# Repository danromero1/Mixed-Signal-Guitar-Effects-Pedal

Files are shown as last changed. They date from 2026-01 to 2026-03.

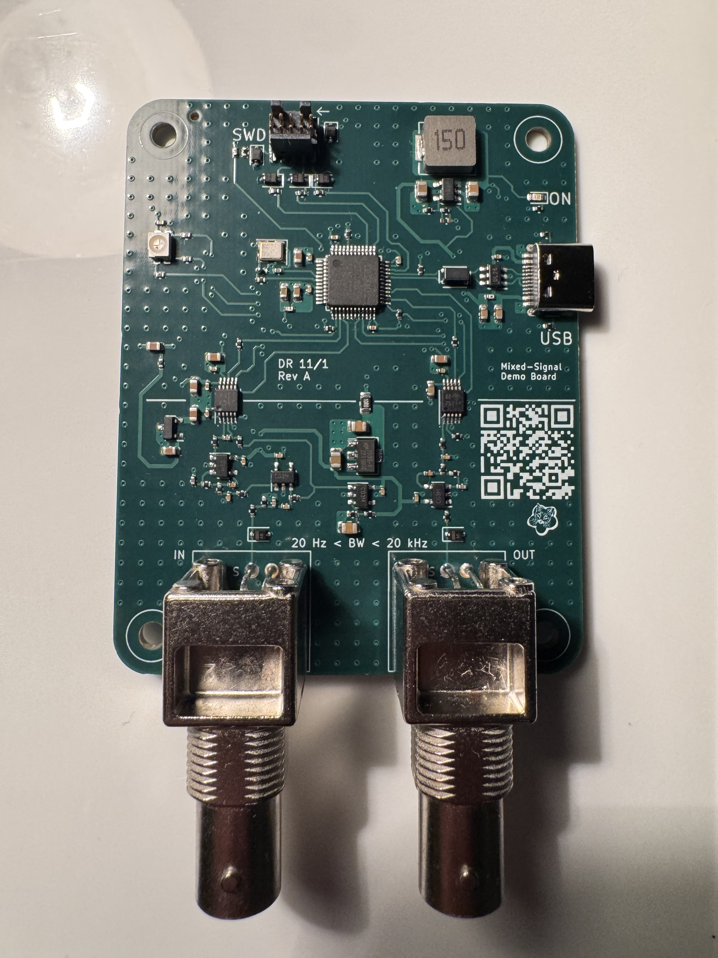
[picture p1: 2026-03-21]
docs/images/assembled_board.png

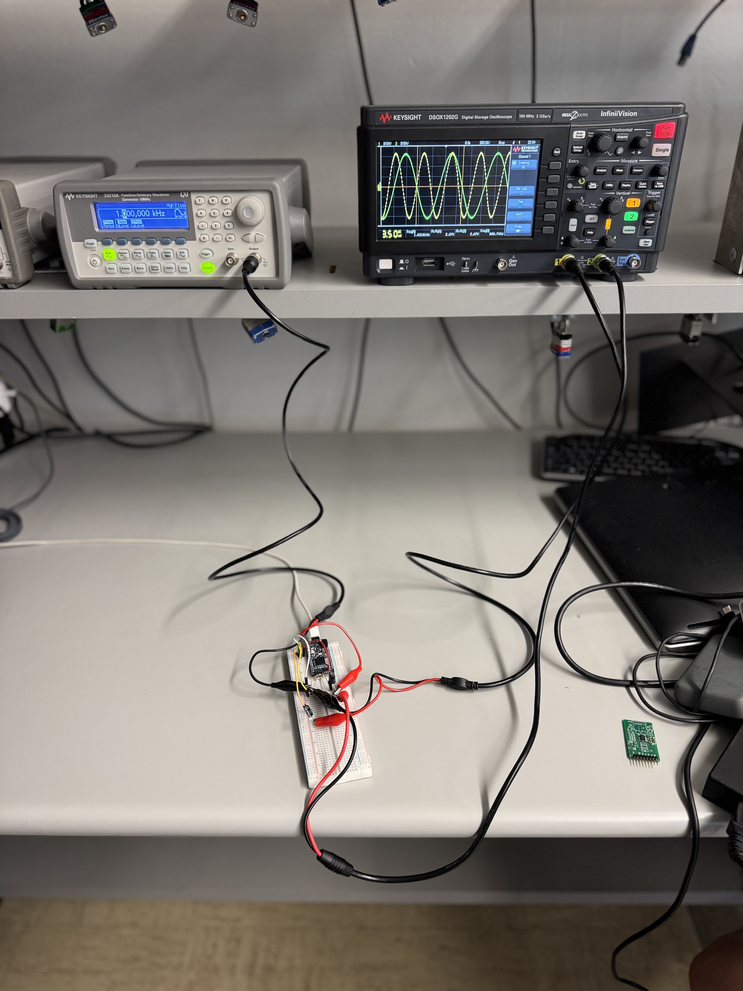
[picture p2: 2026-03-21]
docs/analysis/adc_dma_dac_validation.jpg

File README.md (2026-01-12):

# Mixed-Signal Guitar Effects Pedal





A standalone programmable guitar effects pedal implemented on a custom mixed-signal embedded platform with real-time DSP processing on an STM32 microcontroller.

---

## Overview

This project is the end-to-end design and bring-up of a custom 4-layer mixed-signal embedded platform for real-time audio acquisition, digital signal processing, and playback. An external high-resolution ADC and DAC interface with an STM32 microcontroller to enable deterministic, low-latency audio processing in a standalone system operating without a host PC.

The analog front end provides a high-impedance guitar input stage, precision biasing, and a 3rd-order Butterworth anti-aliasing filter to condition signals prior to conversion. Reconstruction filtering and low-noise output buffering suppress imaging artifacts and maintain low distortion across the audible band. PCB layout emphasizes controlled return paths, analog–digital domain isolation, low-impedance grounding, and consistent impedance to minimize coupling between sensitive analog circuitry and high-speed digital switching.

Power delivery is implemented using a USB-C input feeding a multi-rail regulation architecture to support low-noise analog supplies and regulated digital rails. All power stages and filter networks were simulated and validated in LTspice prior to layout. Decoupling and bypass networks were optimized per device requirements to ensure supply stability under dynamic load conditions.

Firmware is developed bare-metal in STM32CubeIDE using timer-triggered ADC sampling, DMA-based double buffering, and deterministic interrupt scheduling. Digital signal processing algorithms—including soft-clipping distortion, equalization, and filtering—are implemented in C using the CMSIS-DSP library on a Cortex-M4 FPU platform. The system targets a 48 kHz sample rate with sub-5 ms end-to-end latency to preserve instrument responsiveness.

The platform serves as a practical environment for developing embedded firmware architecture, hardware–software co-design techniques, signal integrity practices, and real-time performance analysis while producing a functional guitar effects processor from schematic to working prototype.

---

## Key Objectives

- Design and validate a professional-grade mixed-signal PCB for low-noise audio applications  
- Implement deterministic real-time audio processing on embedded hardware  
- Develop practical experience with ADC/DAC interfacing, buffering, and latency management  
- Integrate hardware bring-up, firmware development, and signal characterization into a complete system  

---

## Features

### Hardware
- STM32 microcontroller with floating-point acceleration  
- External high-resolution ADC and DAC for audio conversion  
- 4-layer PCB optimized for signal integrity and power integrity  
- 3rd-order Butterworth analog anti-aliasing filter  
- USB-C powered multi-rail regulation architecture  

### DSP
- Bare-metal real-time audio pipeline  
- DMA-based double buffering  
- Soft-clipping distortion processing  
- Digital equalization and filtering  
- Deterministic sampling and low-latency operation  

---

## Technical Stack

### Hardware
- STM32 Microcontroller (ARM Cortex-M4 with FPU)  
- External high-resolution ADC and DAC  
- 4-layer PCB with controlled impedance and solid reference planes  
- USB-C power delivery and multi-rail regulation  

### Software & Tools
- KiCad – Schematic capture and PCB layout  
- STM32CubeIDE – Bare-metal firmware development  
- CMSIS-DSP – Optimized DSP library  
- LTspice – Circuit simulation and filter verification  
- C/C++ – Embedded firmware implementation  

---

## Design Process

### Circuit Design & Simulation
Analog input and output stages were designed for guitar signal conditioning, biasing, and bandwidth control. A 3rd-order Butterworth anti-aliasing filter was simulated and verified in LTspice along with ADC/DAC interfacing and power regulation networks.

### PCB Layout (4-Layer Stack-Up)

- **Layer 1:** Top signal layer (components, sensitive analog routing, high-speed digital signals)  
- **Layer 2:** Solid ground plane for low-impedance return paths and noise control  
- **Layer 3:** Secondary reference plane for shielding and analog/digital isolation  
- **Layer 4:** Bottom signal layer for routing and power distribution  

**Design considerations include:**
- Analog and digital domain isolation  
- Controlled impedance routing for high-speed signals  
- Low-inductance return paths and continuous reference planes  
- Robust decoupling and power integrity practices  

### Firmware Architecture

Firmware configures ADC, DAC, timers, DMA, and interrupt scheduling to form a deterministic real-time audio pipeline. Audio samples are acquired using timer-triggered ADC conversions, buffered via DMA, processed in interrupt callbacks, and streamed to the DAC with minimal jitter and latency.

DSP algorithms are implemented in C using CMSIS-DSP primitives and floating-point arithmetic to accelerate development and maintain numerical stability.

---

## Development Status

### Completed
- Schematic design and circuit simulation  
- 3rd-order Butterworth filter design and verification  
- 4-layer PCB layout and stack-up definition  
- Component selection and BOM creation  

### In Progress
- Bare-metal firmware development  
- Real-time DSP implementation  
- PCB fabrication and assembly  

### Planned
- Hardware bring-up and validation  
- Audio performance measurement and characterization  
- Enclosure design and mechanical integration  
- Additional DSP effects (chorus, delay, reverb)  

---

## Technical Specifications

### Audio Path
- Input Impedance: 1 MΩ  
- Sample Rate: 48 kHz  
- Bit Depth: 16–24 bit (ADC dependent)  
- Frequency Response: 20 Hz – 20 kHz  
- Anti-Aliasing Filter: 3rd-order Butterworth, fc ≈ 20 kHz  

### Power
- Input: USB-C (5 V)  
- Internal Rails: 3.3 V (digital), ±5 V or +9 V (analog)  
- Estimated Current Consumption: 200–300 mA  

### Processing
- MCU: STM32 ARM Cortex-M4 with FPU  
- Target End-to-End Latency: < 5 ms  

---

## Engineering Focus

This project provides hands-on experience in:

- Mixed-signal PCB design and layout techniques  
- Real-time embedded firmware development  
- DMA-based buffering and interrupt-driven architectures  
- Analog signal conditioning and filter design  
- Audio signal processing fundamentals  
- Hardware bring-up and debugging on custom PCBs  
- Hardware–software co-design tradeoffs  

---

## Roadmap

### Phase 1 — Core Development (Current)
- Complete DSP firmware implementation  
- Fabricate and assemble PCB  
- Initial bring-up and debugging  

### Phase 2 — Refinement
- Audio performance characterization  
- Latency and CPU utilization optimization  
- PCB revision based on test results  

### Phase 3 — Enhancement
- Additional DSP effects  
- USB parameter control interface  
- Enclosure design and fabrication  

---

## References

### DSP
- *The Scientist and Engineer's Guide to Digital Signal Processing* — Steven W. Smith  
- *Understanding Digital Signal Processing* — Richard G. Lyons  
- *Small Signal Audio Design* — Douglas Self  

### Application Notes
- STM32 Audio Processing Application Notes  
- High-Speed PCB Design Guidelines  
- Audio ADC/DAC Interface Best Practices  

---

## License

This project is licensed under the MIT License. See the [LICENSE](LICENSE) file for details.

---

## Contact

**Daniel Romero**  
Email: daniel.romero@ieee.org  
Portfolio: https://electricalromero.com  
LinkedIn: https://www.linkedin.com/in/daniel-romero-ee/  

---

_Last updated: January 2026_

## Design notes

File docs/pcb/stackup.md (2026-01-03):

# PCB Stackup

This board uses a 4-layer stackup optimized for mixed-signal audio processing and embedded digital systems.

## Layer Configuration

| Layer | Name | Function |
|---:|---|---|
| L1 | Top (F.Cu)  | Signal routing and component placement |
| L2 | Inner 1 | Solid ground plane |
| L3 | Inner 2 | Solid ground plane |
| L4 | Bottom (B.Cu) | Secondary signal routing and low-speed interconnects |

## Design Rationale

- Dual internal ground planes provide low-inductance return paths for both analog and digital signals.
- Continuous, unbroken ground planes minimize EMI, ground bounce, and noise coupling in mixed-signal paths.
- Analog and digital circuits reference the same ground system to avoid return-path discontinuities.
- Critical signal routing is kept on the top layer with immediate reference to the adjacent ground plane.
- Bottom layer routing is used primarily for non-critical signals and escape routing.

## Mixed-Signal Considerations

- No split ground planes are used to prevent unintended return path interruptions.
- Stitching vias are placed near layer transitions to maintain return path continuity.
- Power and signal routing are arranged to minimize coupling between high-speed digital and sensitive analog sections.

## Notes

- Stackup prioritizes signal integrity and noise performance over routing density.
- Layout decisions follow standard mixed-signal PCB design best practices.

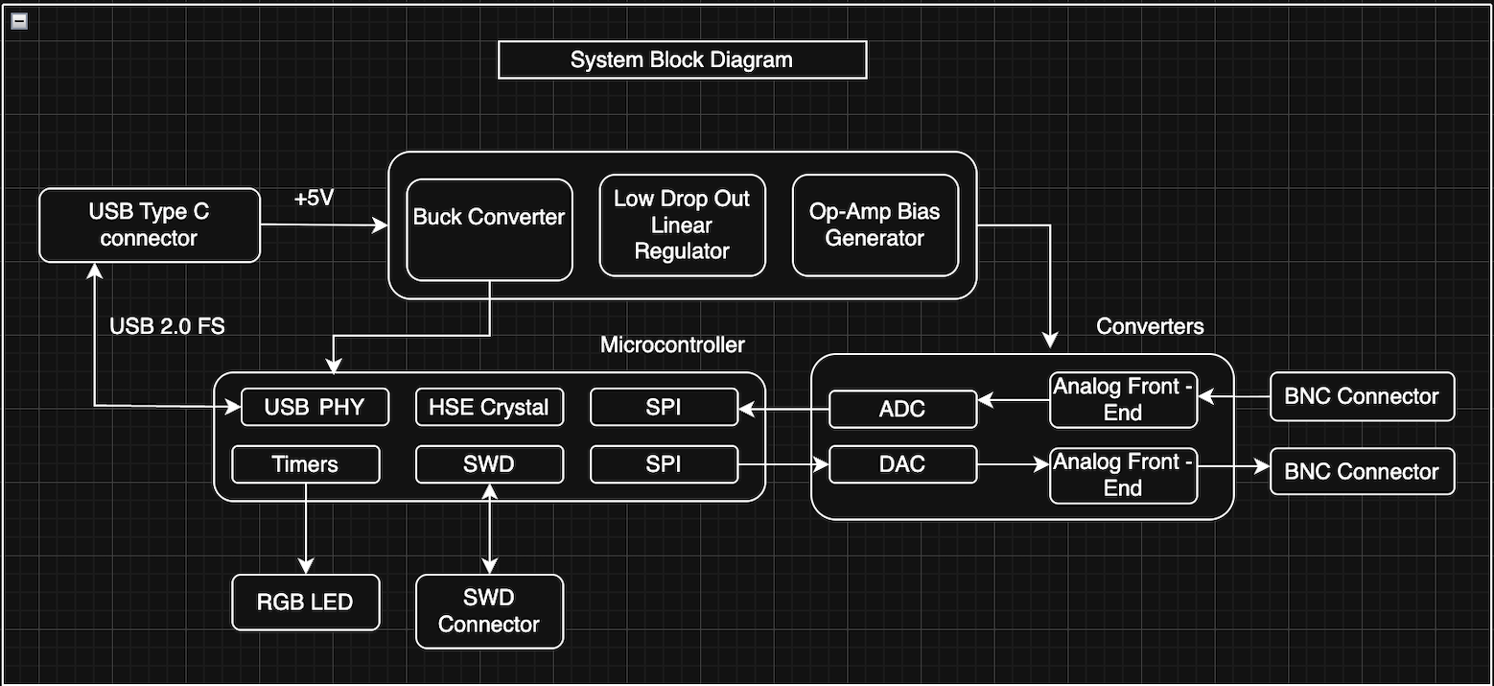
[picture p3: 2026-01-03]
docs/images/Block Diagram.png

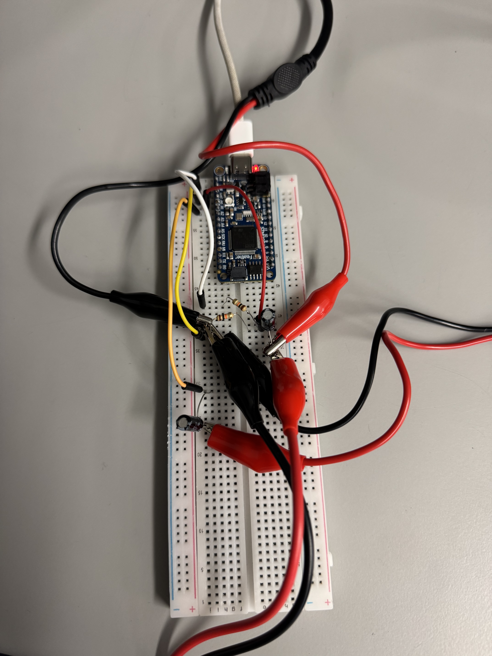
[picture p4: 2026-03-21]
docs/analysis/STM32F4_signal_chain_prototype.jpg

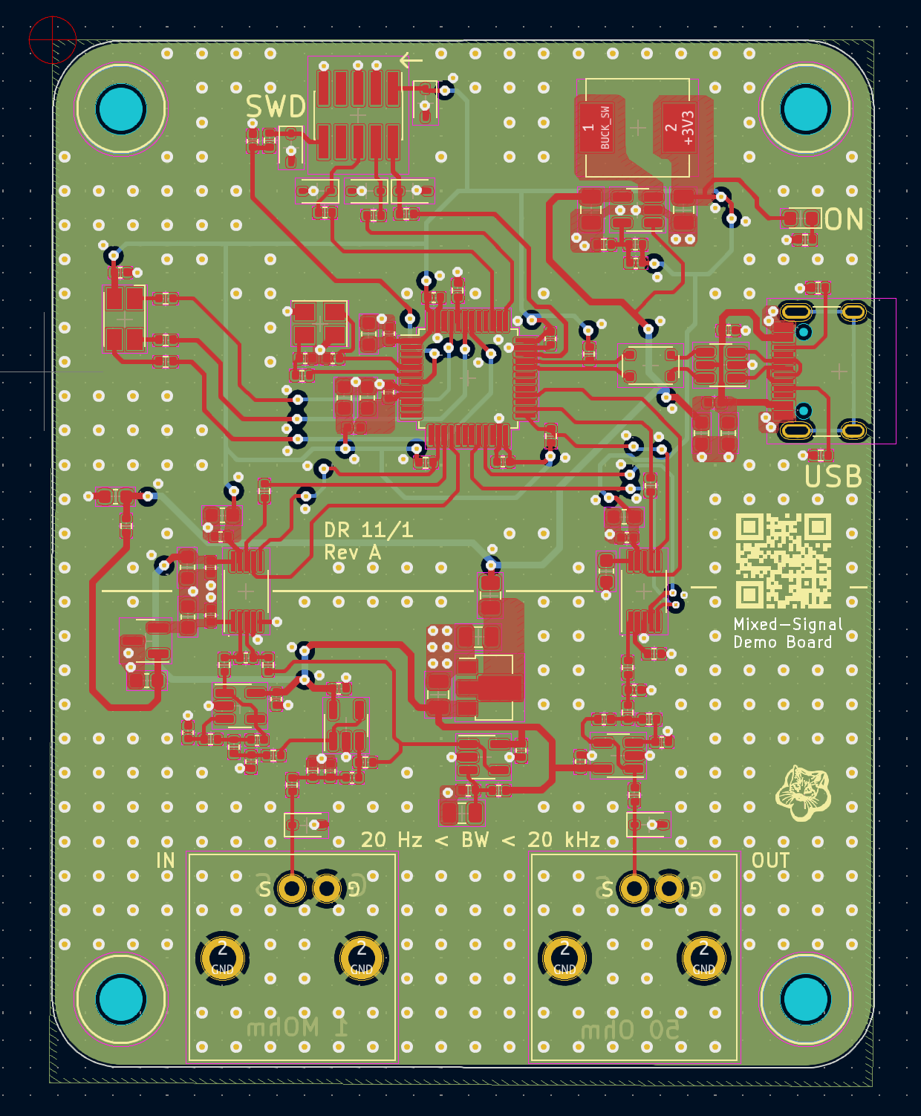
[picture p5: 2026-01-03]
docs/images/mixed_signal_pcb_routing.png

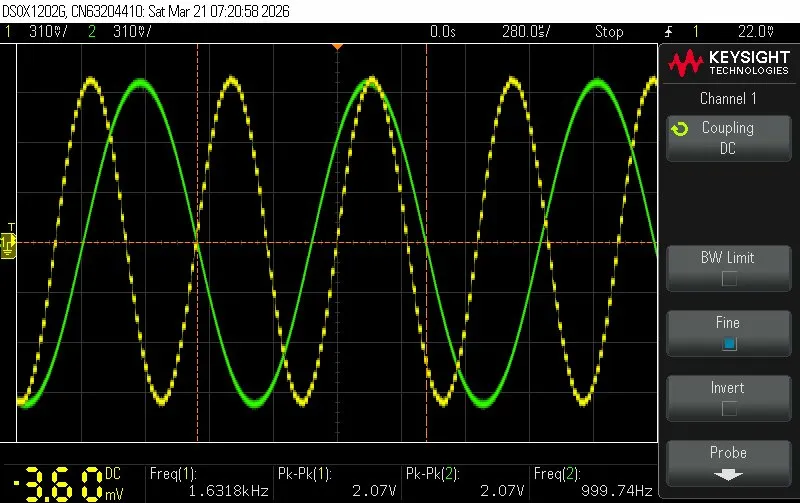
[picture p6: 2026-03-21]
docs/analysis/scope.webp

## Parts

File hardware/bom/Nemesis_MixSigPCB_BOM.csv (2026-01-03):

Source: | /Users/danielromero/Desktop/Projects/Mixed-Signal Hardware Design Project (Guitar Pedal)/MixSigCourse-B-KiCad7-Files/Nemesis-MixSigPCB.kicad_sch
Date: | Sunday, November 02, 2025 at 11:34:06 AM
Tool: | Eeschema 7.0.10
Generator: | /Applications/KiCad/KiCad.app/Contents/SharedSupport/plugins/bom_csv_grouped_by_value_with_fp.py
Component Count: | 114
Ref | Qty | Value | Cmp name | Footprint | Description | Vendor | DNP | Manufacturer | Manufacturer Part Number
C100, C101, C206, C207, C402 | 5 | CL10A105KB8NNNC | C | Capacitor_SMD:C_0603_1608Metric | Unpolarized capacitor |  |  | Samsung Electro-Mechanics | CL10A105KB8NNNC
C102, C103, C104, C105, C107 | 5 | CL21A226MAQNNNE | C | Capacitor_SMD:C_0805_2012Metric | Unpolarized capacitor |  |  | Samsung Electro-Mechanics | CL21A226MAQNNNE
C106 | 1 |  | C | Capacitor_SMD:C_0402_1005Metric | Unpolarized capacitor
C108, C201, C202, C203, C204, C210, C211, C212, C301, C302, C306, C311, C313, C314, C401, C406 | 16 | CL05B104KO5NNNC | C | Capacitor_SMD:C_0402_1005Metric | Unpolarized capacitor |  |  | Samsung Electro-Mechanics | CL05B104KO5NNNC
C200, C308, C309, C310, C312, C315, C400 | 7 | CL10A106MA8NRNC | C | Capacitor_SMD:C_0603_1608Metric | Unpolarized capacitor |  |  | Samsung Electro-Mechanics | CL10A106MA8NRNC
C205 | 1 | CL05B103KB5NNNC | C | Capacitor_SMD:C_0402_1005Metric | Unpolarized capacitor |  |  | Samsung Electro-Mechanics | CL05B103KB5NNNC
C208, C209 | 2 | CL05C100JB5NNNC | C | Capacitor_SMD:C_0402_1005Metric | Unpolarized capacitor |  |  | Samsung Electro-Mechanics | CL05C100JB5NNNC
C300, C304, C307, C404 | 4 | CL05C151JB5NNNC | C | Capacitor_SMD:C_0402_1005Metric | Unpolarized capacitor |  |  | Samsung Electro-Mechanics | CL05C151JB5NNNC
C303, C305, C403, C405 | 4 | 0402B102K500NT | C | Capacitor_SMD:C_0402_1005Metric | Unpolarized capacitor |  |  | FH (Guangdong Fenghua Advanced Tech) | 0402B102K500NT
D100 | 1 | 19-217/GHC-YR1S2/3T | LED | LED_SMD:LED_0603_1608Metric | Light emitting diode |  |  | Everlight Elec | 19-217/GHC-YR1S2/3T
D200 | 1 | MHPA3528RGBCT | ASMB-MTB1-0A3A2 | LED_SMD:MHPA3528RGBCT | Tricolor Black Surface LED, Common Anode Pin 4, PLCC-4 |  |  | MEIHUA | MHPA3528RGBCT
D201, D202, D203, D204, D205, D300, D400 | 7 | PESD3V3L1BA,115 | D_TVS | Diode_SMD:D_SOD-323 | Bidirectional transient-voltage-suppression diode |  |  | Nexperia | PESD3V3L1BA,115
H1, H2, H3, H4 | 4 |  | MountingHole | MountingHole:MountingHole_3.2mm_M3 | Mounting Hole without connection
J200 | 1 | TYPE-C-31-M-12 | USB_C_Receptacle_USB2.0 | Connector_USB:USB_C_Receptacle_HRO_TYPE-C-31-M-12 | USB 2.0-only Type-C Receptacle connector |  |  | Korean Hroparts Elec | TYPE-C-31-M-12
J201 | 1 | FTSH-105-01-F-DV-K-TR | SWD_02x05_PinHeader | Connector_PinHeader_1.27mm:PinHeader_2x05_P1.27mm_Vertical_SMD | DIN41612 connector, double row (AB) even pins only, 02x05, script generated (kicad-library-utils/schlib/autogen/connector/) |  |  | Samtec | FTSH-105-01-F-DV-K-TR
J300, J400 | 2 | 031-5640 | Conn_Coaxial | Custom_RF:AMPHENOL-BNC-031-5640-1010 | coaxial connector (BNC, SMA, SMB, SMC, Cinch/RCA, LEMO, ...) |  |  | Amphenol ICC | 031-5640
L100, L200 | 2 | SDCL1005C10NJTDF | L | Inductor_SMD:L_0402_1005Metric | Inductor |  |  | Sunlord | SDCL1005C10NJTDF
L101 | 1 | MWSA0603S-150MT | L | Inductor_SMD:L_Sunlord_MWSA0603S | Inductor |  |  | Sunlord | MWSA0603S-150MT
L201 | 1 | CMF3216F-900-2P-T | EMI_Filter_LL_1423 | Inductor_SMD:L_CommonModeChoke_CMF3216F-900-2P-T |  |  |  | HYHONGYEX | CMF3216F-900-2P-T
R100 | 1 | 0805W8F100JT5E | R | Resistor_SMD:R_0805_2012Metric | Resistor |  |  | UNI-ROYAL(Uniroyal Elec) | 0805W8F100JT5E
R101 | 1 | 0402WGF1003TCE | R | Resistor_SMD:R_0402_1005Metric | Resistor |  |  | UNI-ROYAL(Uniroyal Elec) | 0402WGF1003TCE
R102, R304, R403 | 3 | 0402WGF2202TCE | R | Resistor_SMD:R_0402_1005Metric | Resistor |  |  | UNI-ROYAL(Uniroyal Elec) | 0402WGF2202TCE
R103, R104, R105, R207, R208, R209, R300, R306, R307 | 9 | 0402WGF1001TCE | R | Resistor_SMD:R_0402_1005Metric | Resistor |  |  | UNI-ROYAL(Uniroyal Elec) | 0402WGF1001TCE
R200, R202, R203, R401 | 4 | 0402WGF1002TCE | R | Resistor_SMD:R_0402_1005Metric | Resistor |  |  | UNI-ROYAL(Uniroyal Elec) | 0402WGF1002TCE
R201, R309, R400 | 3 | 0402WGF0000TCE | R | Resistor_SMD:R_0402_1005Metric | Resistor |  |  | UNI-ROYAL(Uniroyal Elec) | 0402WGF0000TCE
R204 | 1 | 0402WGF1501TCE | R | Resistor_SMD:R_0402_1005Metric | Resistor |  |  | UNI-ROYAL(Uniroyal Elec) | 0402WGF1501TCE
R205, R206 | 2 | 0402WGF5101TCE | R | Resistor_SMD:R_0402_1005Metric | Resistor |  |  | UNI-ROYAL(Uniroyal Elec) | 0402WGF5101TCE
R210, R211, R212, R213, R308, R405 | 6 | 0402WGF499JTCE | R | Resistor_SMD:R_0402_1005Metric | Resistor |  |  | UNI-ROYAL(Uniroyal Elec) | 0402WGF499JTCE
R301, R302 | 2 | 0402WGF2204TCE | R | Resistor_SMD:R_0402_1005Metric | Resistor |  |  | UNI-ROYAL(Uniroyal Elec) | 0402WGF2204TCE
R303, R402 | 2 | 0402WGF6801TCE | R | Resistor_SMD:R_0402_1005Metric | Resistor |  |  | UNI-ROYAL(Uniroyal Elec) | 0402WGF6801TCE
R305, R404 | 2 | 0402WGF1202TCE | R | Resistor_SMD:R_0402_1005Metric | Resistor |  |  | UNI-ROYAL(Uniroyal Elec) | 0402WGF1202TCE
U100 | 1 | HT7533-1 | HT75xx-1-SOT89 | Package_TO_SOT_SMD:SOT-89-3 | 100mA Low Dropout Voltage Regulator, Fixed Output, SOT89 |  |  | Holtek Semicon | HT7533-1
U101 | 1 | TLV62569DBVR | TLV62569DBV | Package_TO_SOT_SMD:SOT-23-5 | High Efficiency Synchronous Buck Converter, Adjustable Output 0.6V-5.5V, 2A, SOT-23-5 |  |  | Texas Instruments | TLV62569DBVR
U102, U300, U301, U401 | 4 | MCP6001T-E/OT | MCP6001-OT | Package_TO_SOT_SMD:SOT-23-5 | 1MHz, Low-Power Op Amp, SOT-23-5 |  |  | Microchip Tech | MCP6001T-E/OT
U200 | 1 | STM32F103CBT6 | STM32F103CBTx | Package_QFP:LQFP-48_7x7mm_P0.5mm | ARM Cortex-M3 MCU, 128KB flash, 20KB RAM, 72MHz, 2-3.6V, 37 GPIO, LQFP-48 |  |  | STMicroelectronics | STM32F103CBT6
U201 | 1 | USBLC6-2SC6 | USBLC6-2SC6 | Package_TO_SOT_SMD:SOT-23-6 | Very low capacitance ESD protection diode, 2 data-line, SOT-23-6 |  |  | STMicroelectronics | USBLC6-2SC6
U302 | 1 | REF3033AIDBZT | REF3033 | Package_TO_SOT_SMD:SOT-23 | 3.3V 50-ppm/°C Max, 50-μA, CMOS Voltage Reference, SOT-23-3 |  |  | Texas Instruments | REF3033AIDBZT
U303 | 1 | ADC141S626CIMM/NOPB | ADC141S626CIMM_NOPB | Package_SO:VSSOP-10_3x3mm_P0.5mm |  |  |  | Texas Instruments | ADC141S626CIMM/NOPB
U400 | 1 | DAC7563TDGSR | DAC7563SDGSR | Package_SO:VSSOP-10_3x3mm_P0.5mm |  |  |  | Texas Instruments | DAC7563TDGSR
Y200 | 1 | 7M16000017 | Crystal_GND24 | Crystal:Crystal_SMD_3225-4Pin_3.2x2.5mm | Four pin crystal, GND on pins 2 and 4 |  |  | TXC Corp | 7M16000017

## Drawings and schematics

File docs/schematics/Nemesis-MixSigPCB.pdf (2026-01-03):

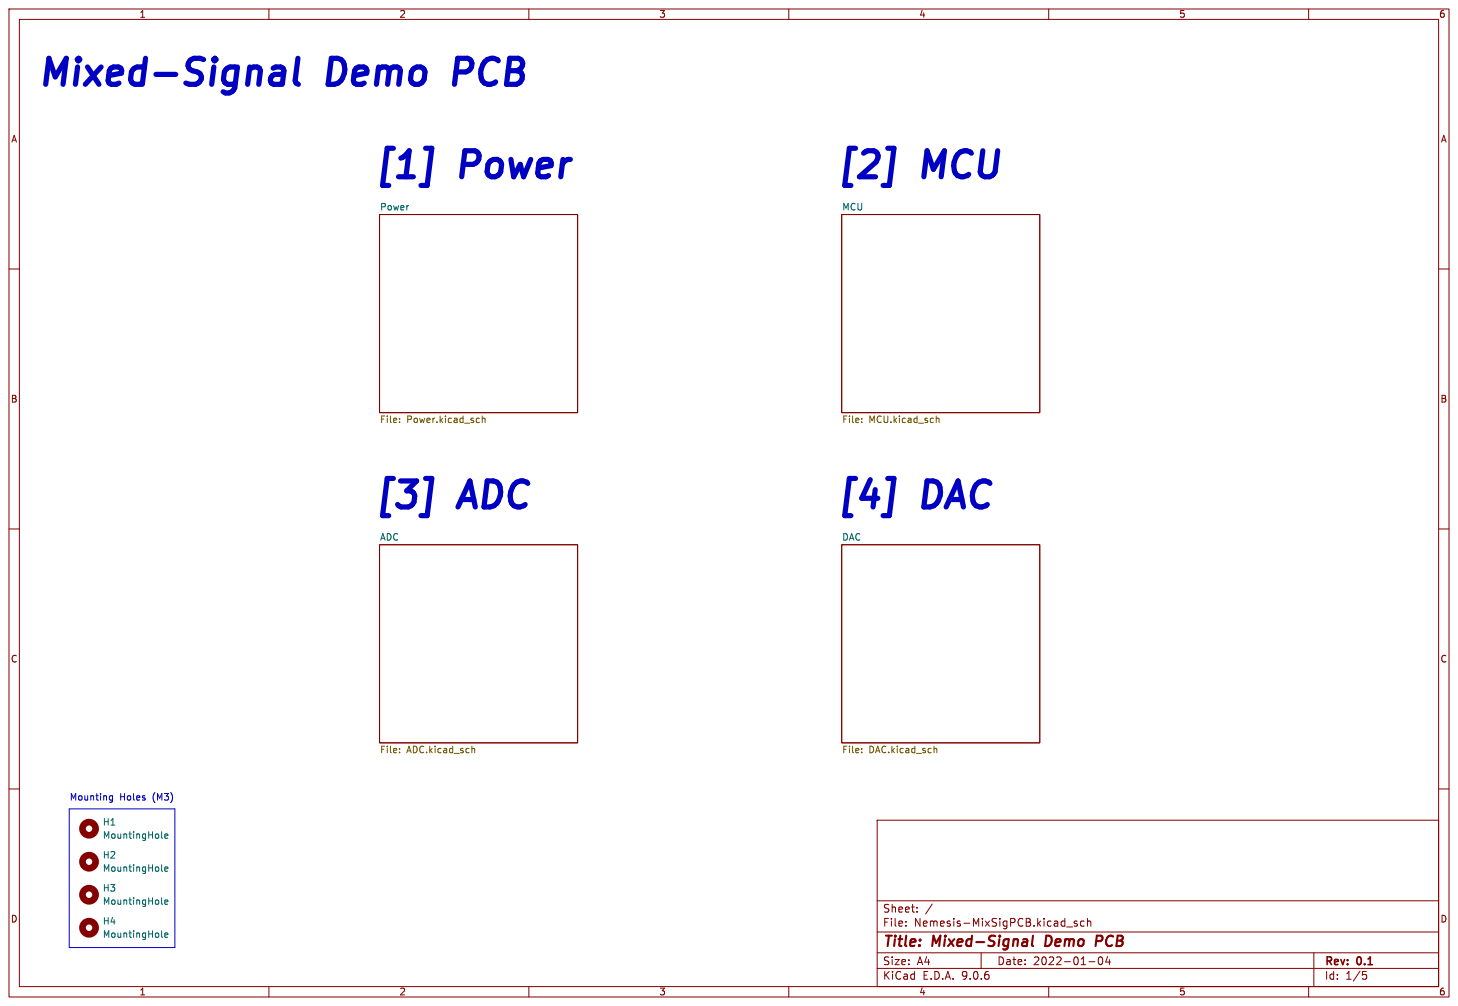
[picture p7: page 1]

[1] Power
Power File: Power.kicad_sch ADC

File: DAC.kicad_sch H3 MountingHole H4 MountingHole H1 MountingHole H2 MountingHole

File: Nemesis-MixSigPCB.kicad_sch Sheet: /

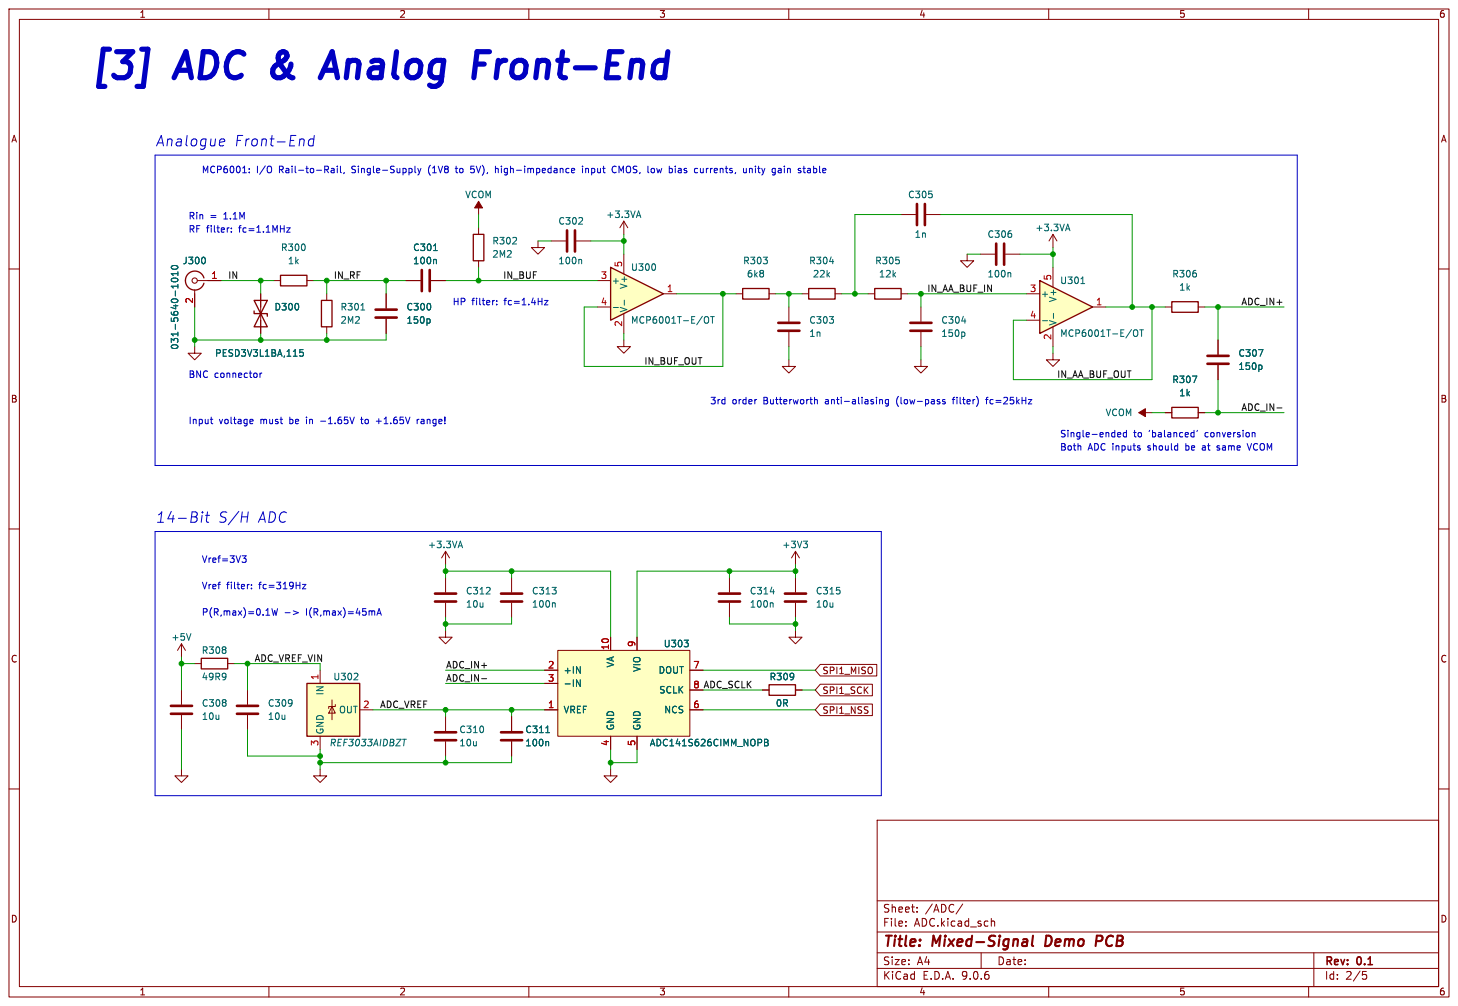
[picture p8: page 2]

File: ADC.kicad_sch Sheet: /ADC/ C312

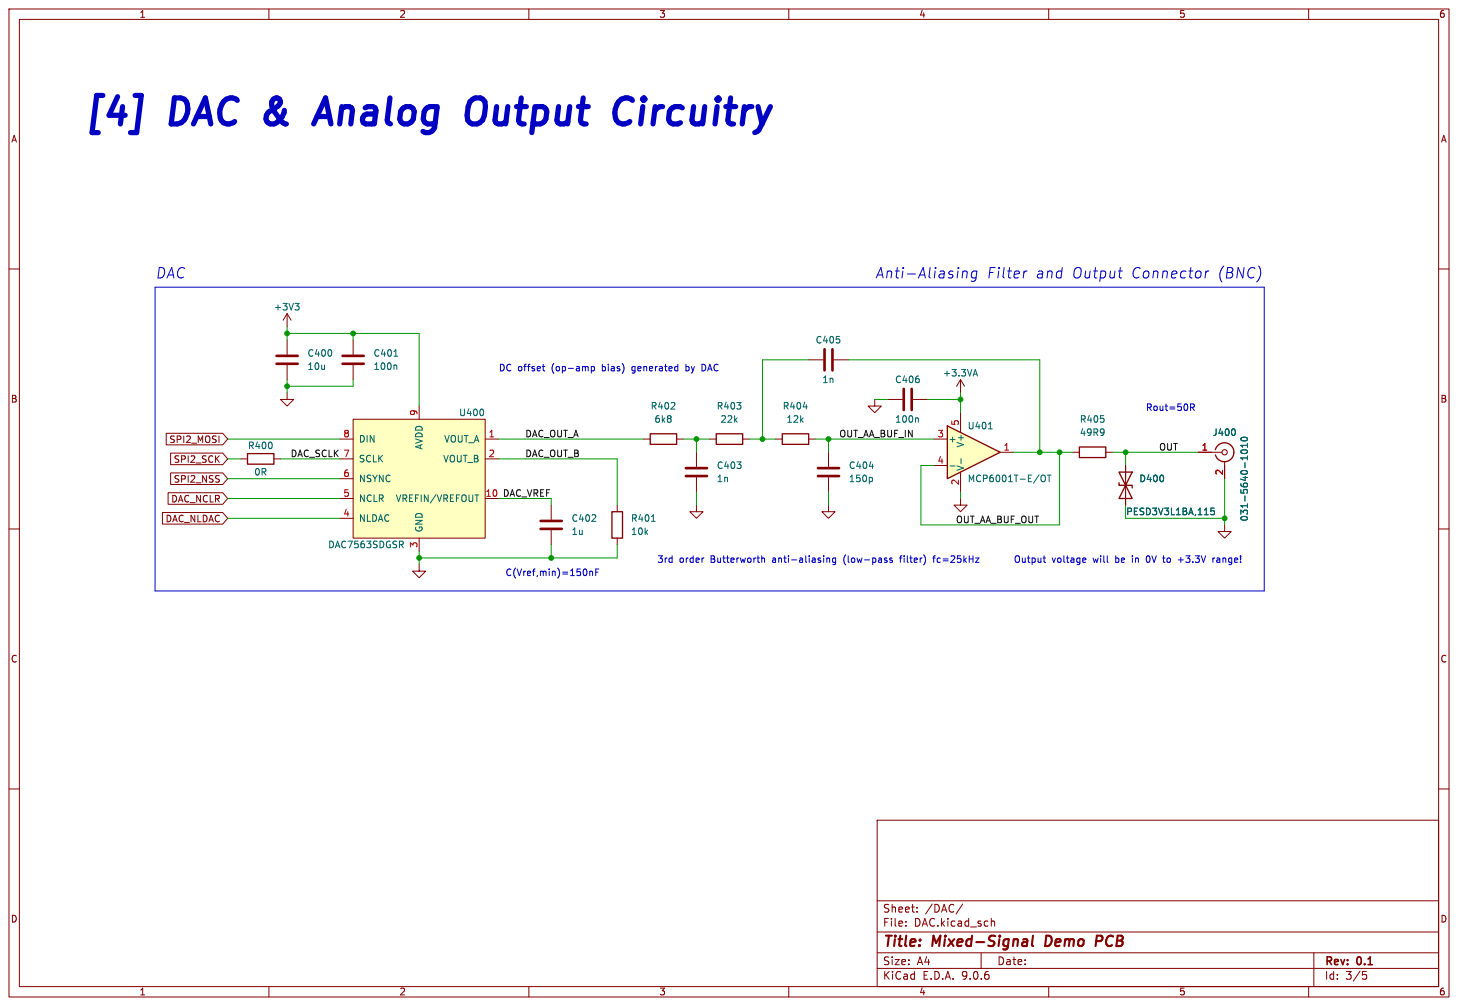
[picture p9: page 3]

File: DAC.kicad_sch Sheet: /DAC/ C404

3 DIN 8 SCLK 7 NSYNC 6 NCLR 5 NLDAC 4 U400 DAC7563SDGSR

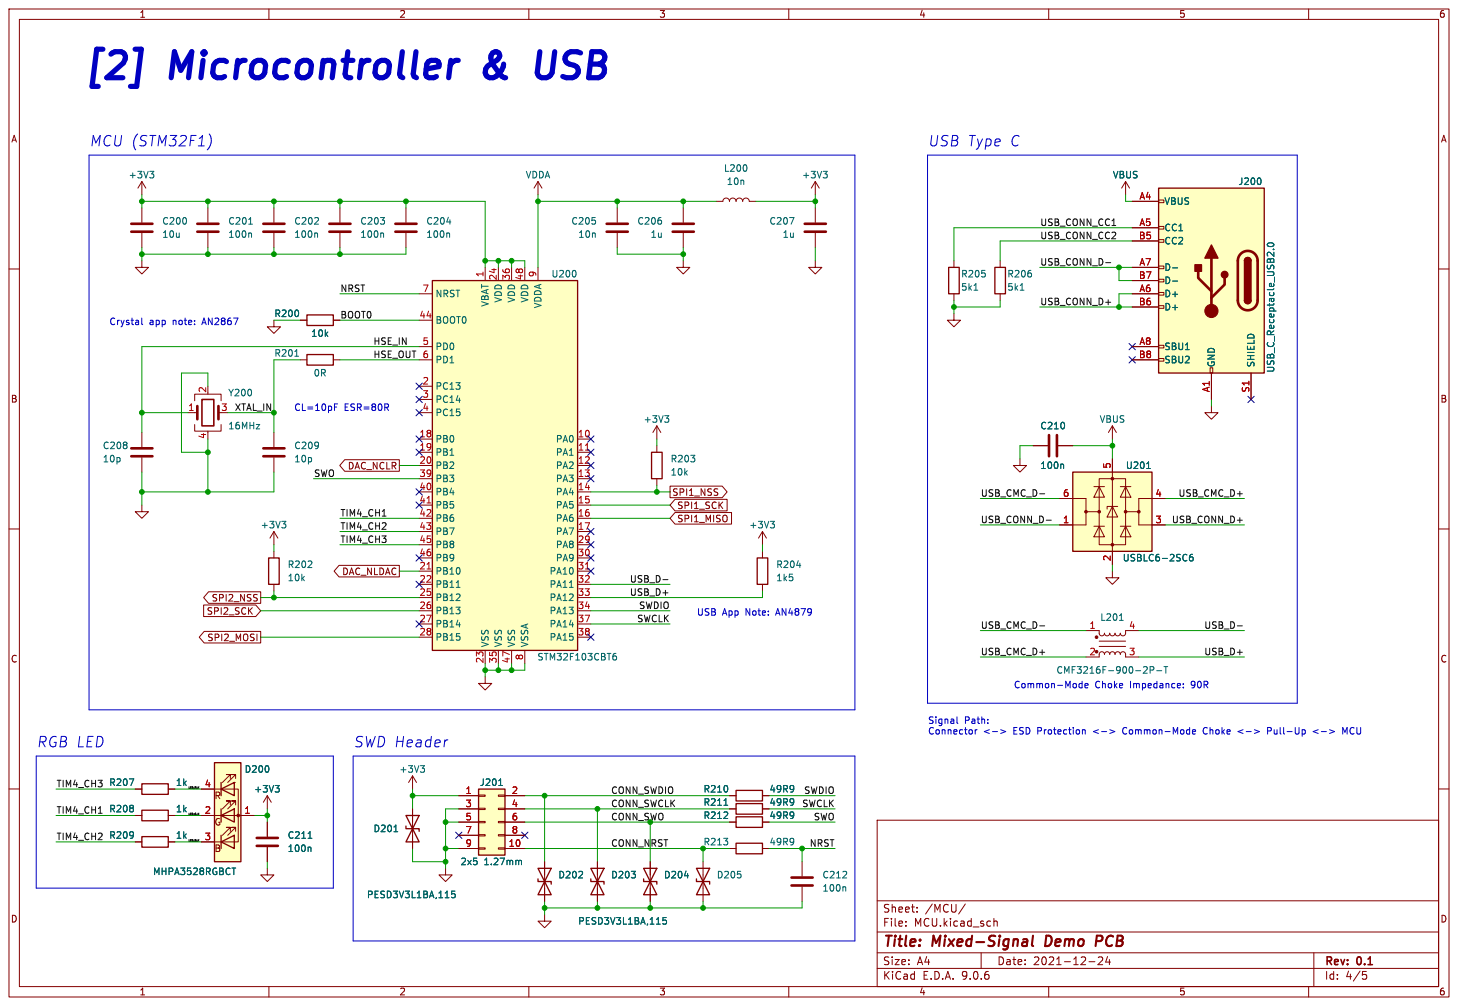
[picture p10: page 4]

1 VSS 23 VDD 24 VSS 35 VDD 36 VSS 47 VDD 48 VSSA

File: MCU.kicad_sch Sheet: /MCU/

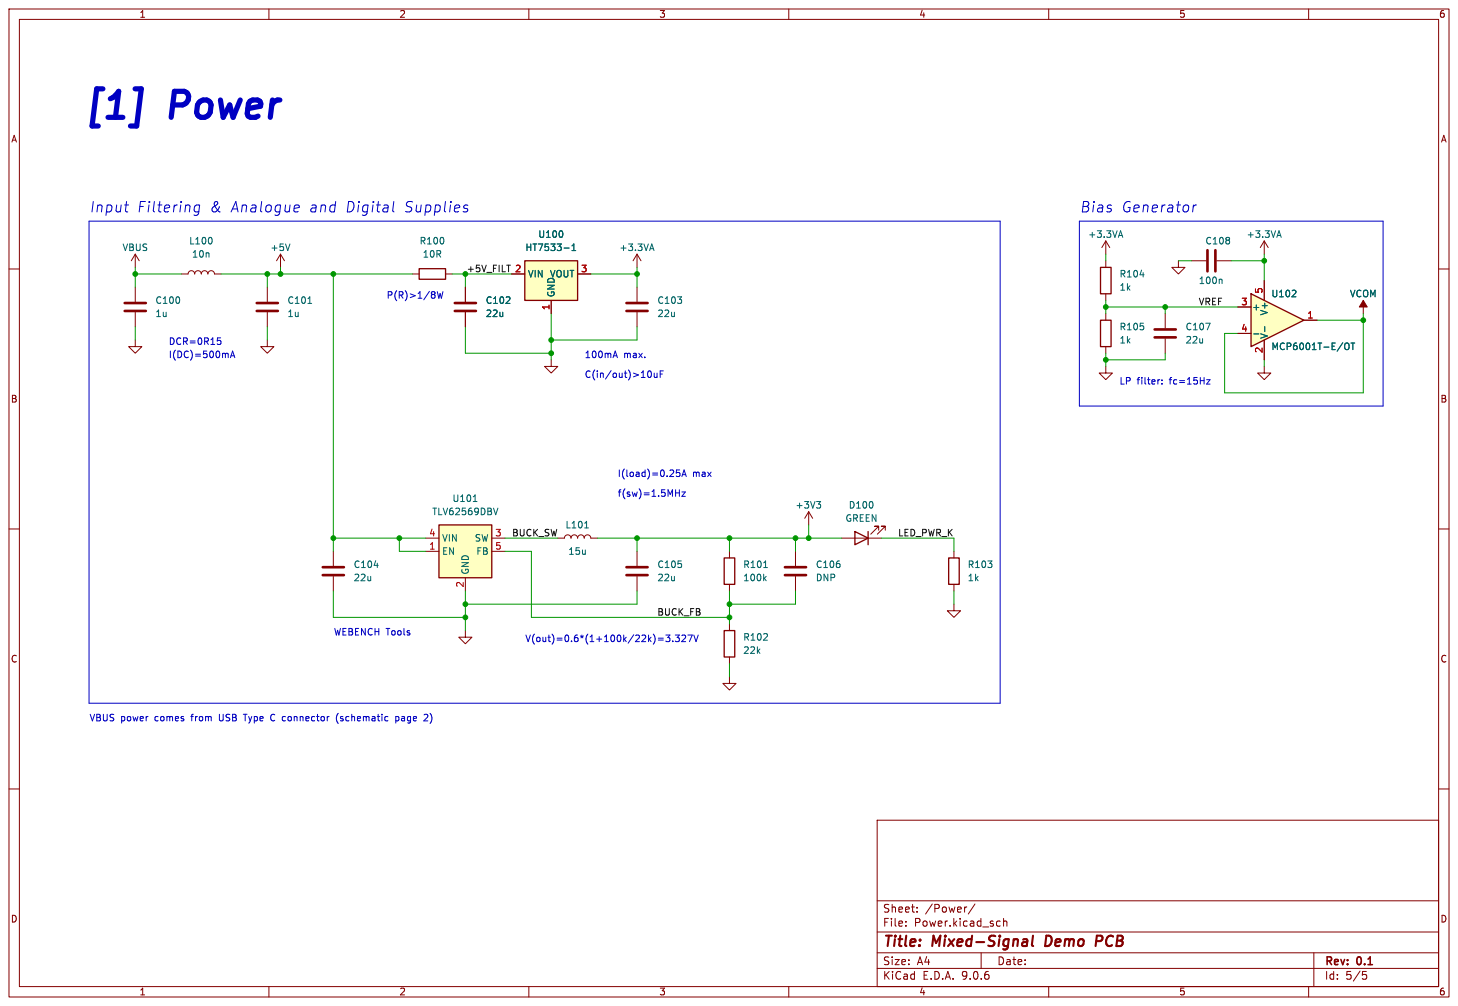
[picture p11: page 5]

Input Filtering & Analogue and Digital Supplies

File: Power.kicad_sch Sheet: /Power/

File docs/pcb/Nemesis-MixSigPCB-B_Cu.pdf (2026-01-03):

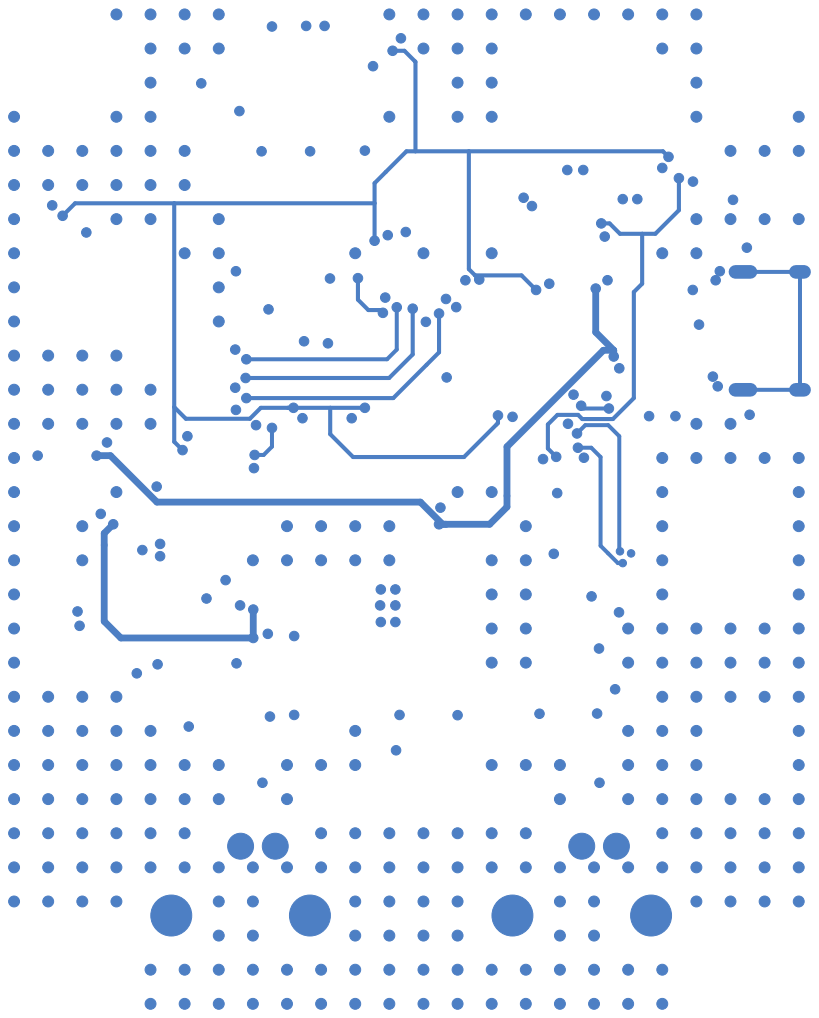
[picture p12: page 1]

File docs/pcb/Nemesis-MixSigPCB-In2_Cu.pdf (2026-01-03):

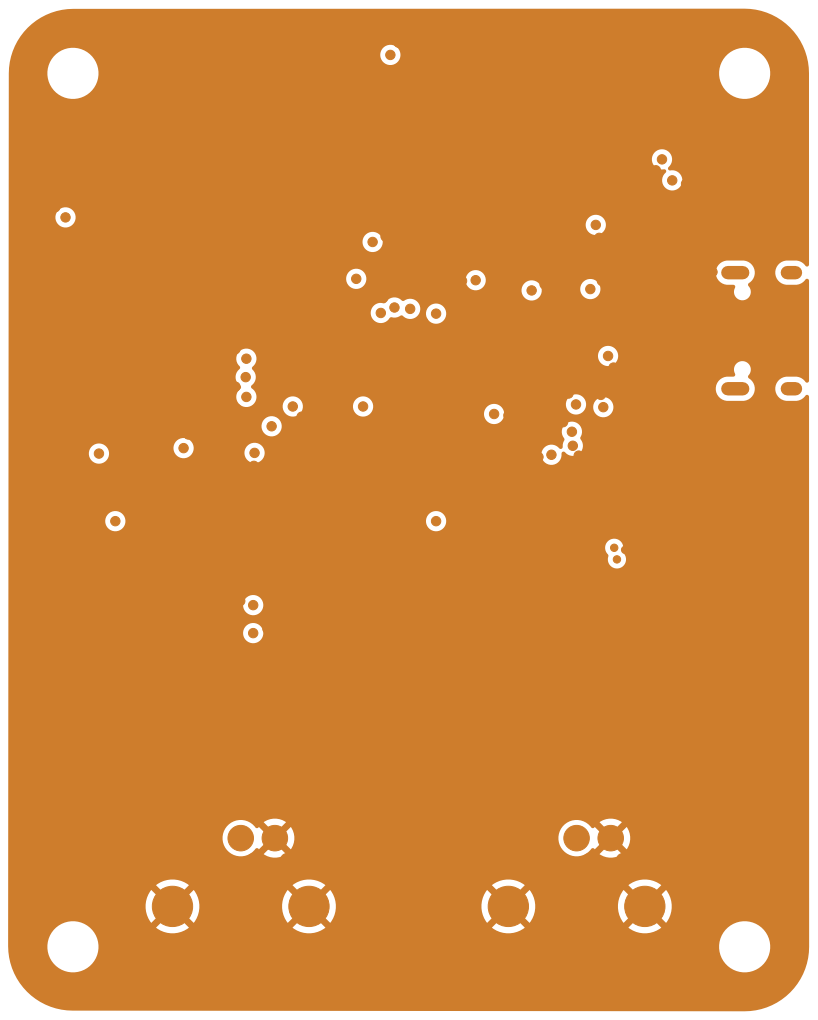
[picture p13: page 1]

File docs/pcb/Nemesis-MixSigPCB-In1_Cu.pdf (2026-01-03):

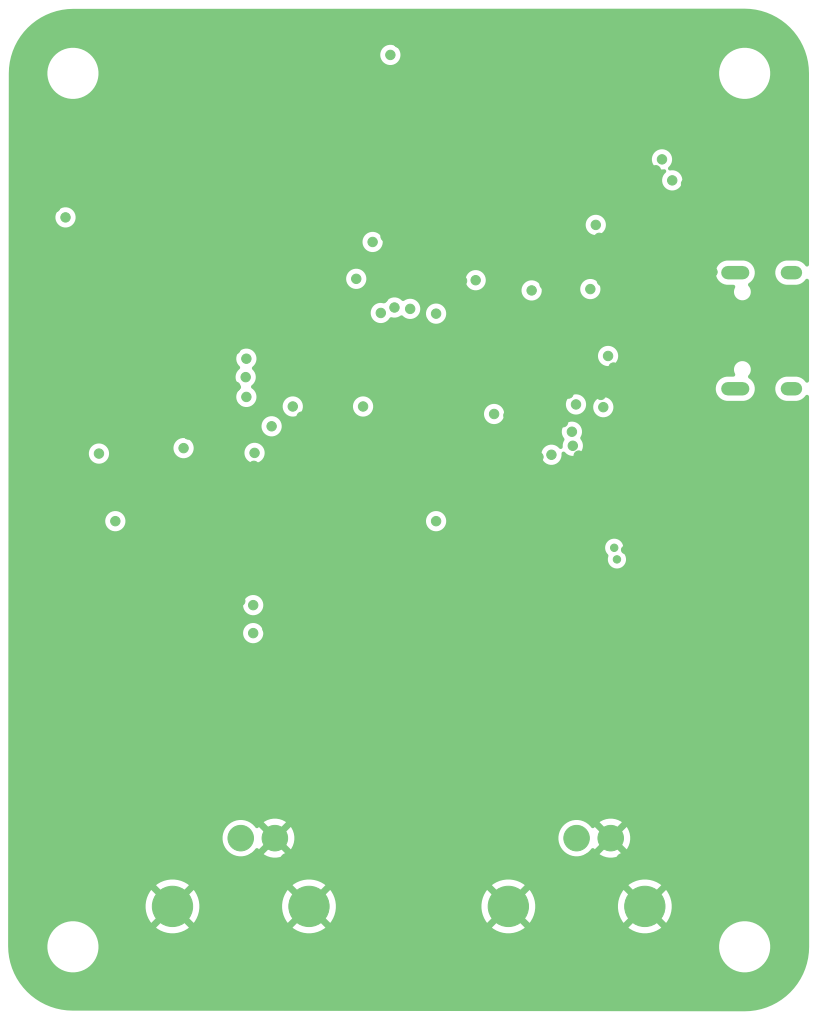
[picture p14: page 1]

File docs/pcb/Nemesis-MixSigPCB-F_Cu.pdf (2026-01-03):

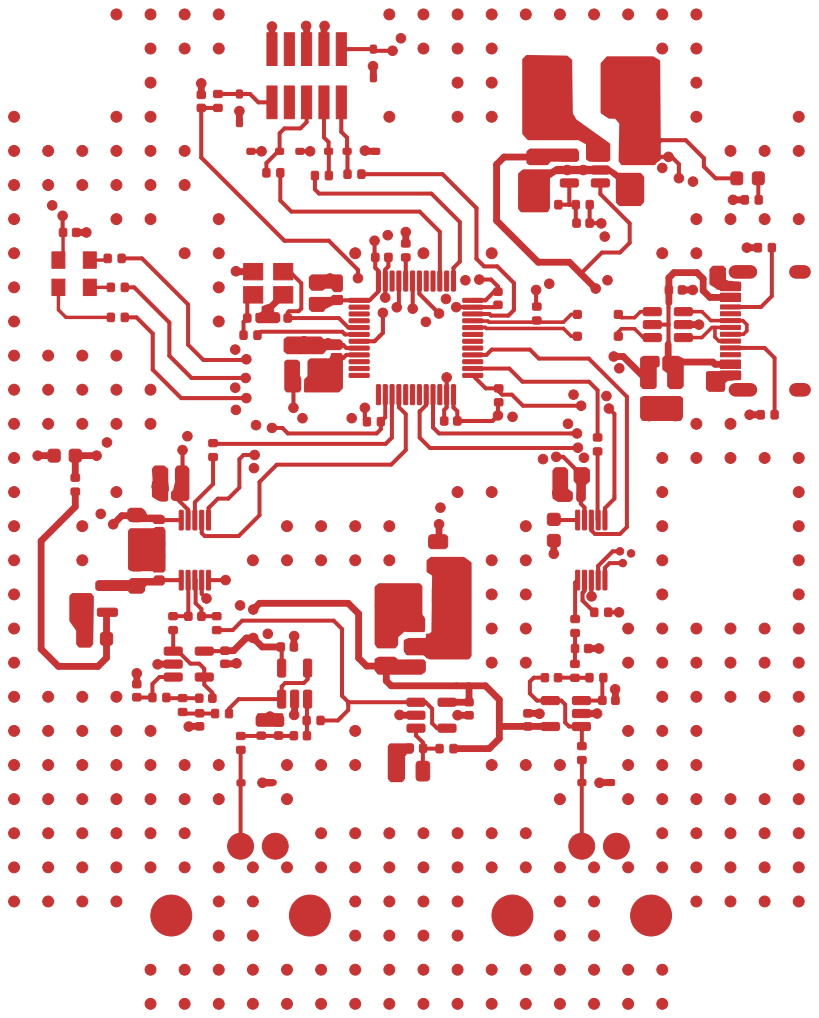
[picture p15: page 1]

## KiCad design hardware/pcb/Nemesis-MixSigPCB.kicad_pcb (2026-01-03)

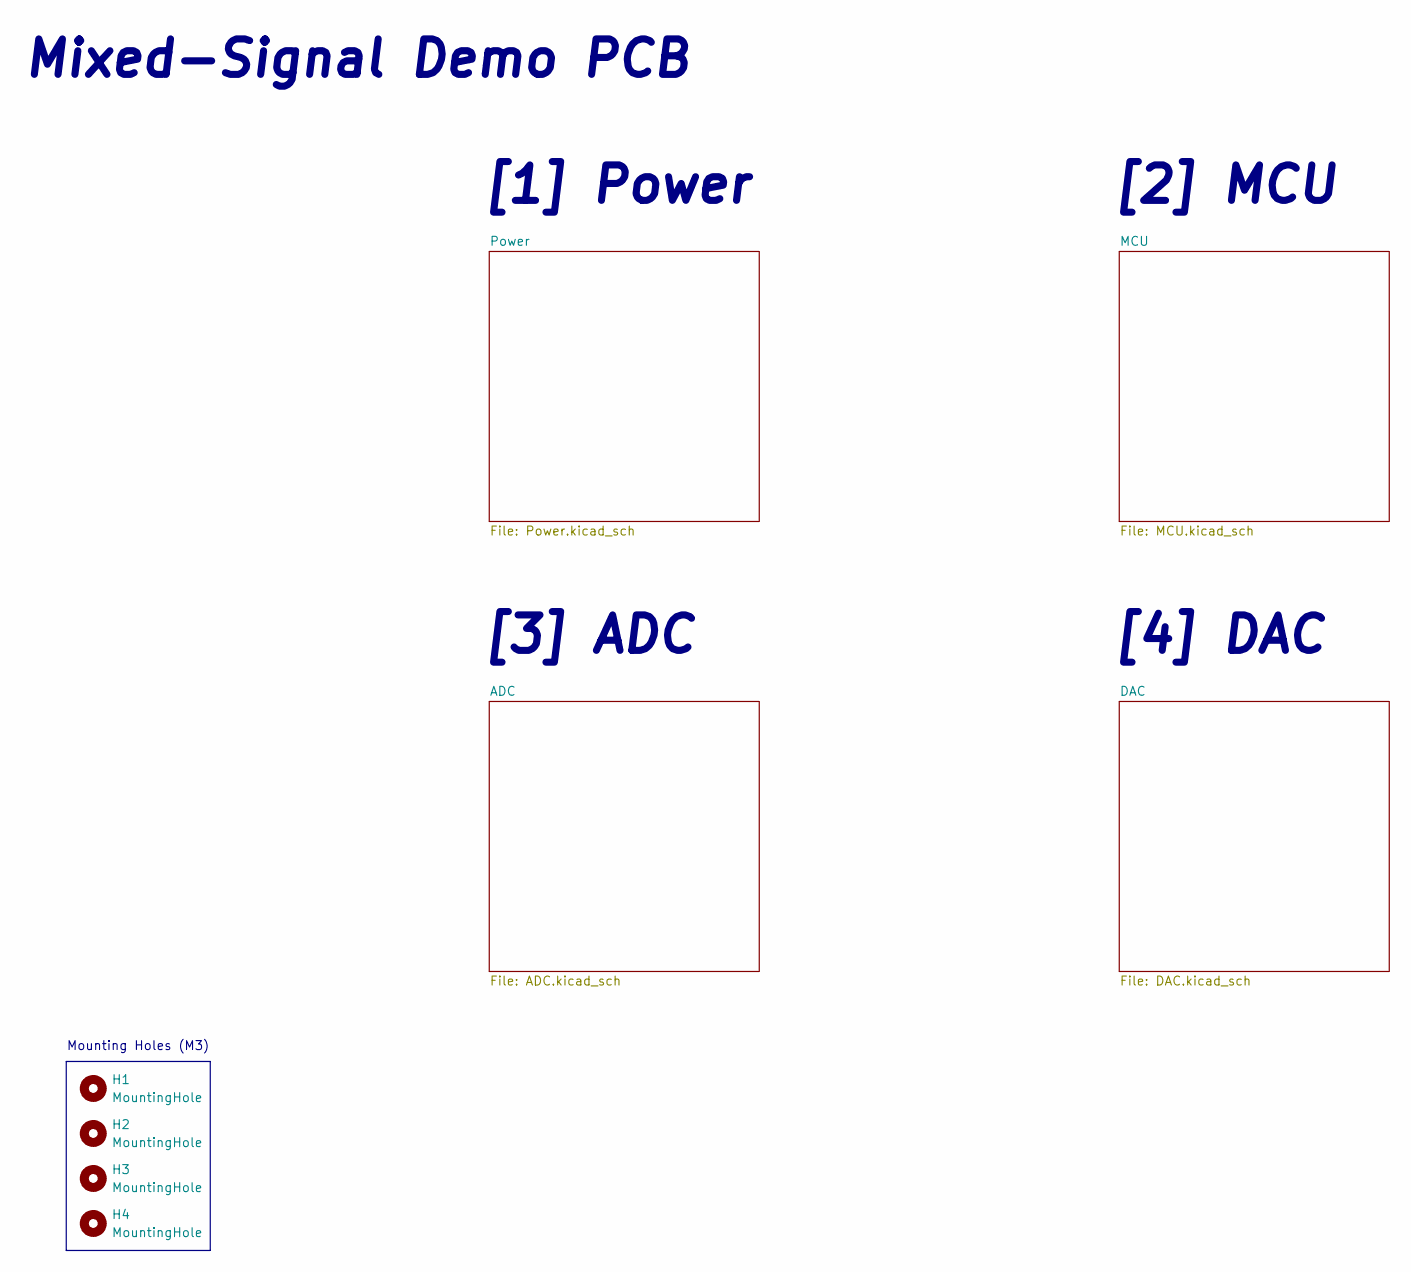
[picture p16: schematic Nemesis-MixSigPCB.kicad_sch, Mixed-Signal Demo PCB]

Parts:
H1, H2, H3, H4: MountingHole; MountingHole_3.2mm_M3

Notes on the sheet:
[4] DAC
Mixed-Signal Demo PCB
[3] ADC
Mounting Holes (M3)
[2] MCU
[1] Power

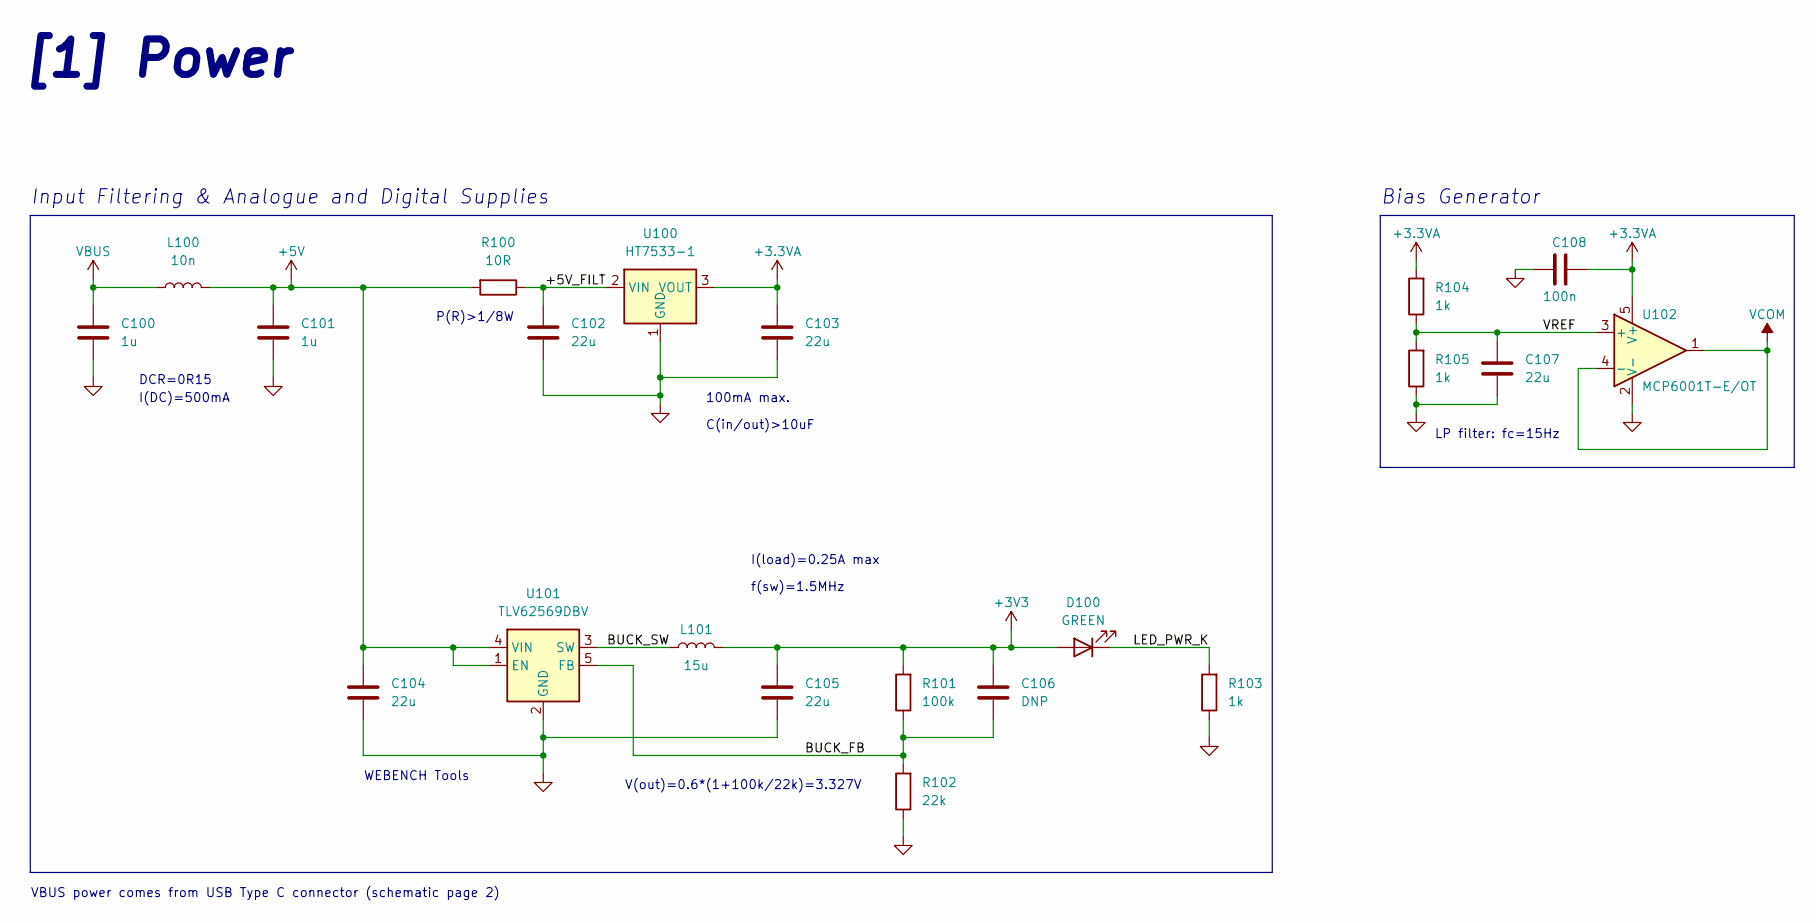
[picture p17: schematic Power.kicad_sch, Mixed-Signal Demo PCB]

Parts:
C100, C101: 1u; C_0603_1608Metric; Manufacturer Part Number CL10A105KB8NNNC
C102, C103, C104, C105, C107: 22u; C_0805_2012Metric; Manufacturer Part Number CL21A226MAQNNNE
C106: DNP; C_0402_1005Metric
C108: 100n; C_0402_1005Metric; Manufacturer Part Number CL05B104KO5NNNC
D100: GREEN; LED_0603_1608Metric; Manufacturer Part Number 19-217/GHC-YR1S2/3T
L100: 10n; L_0402_1005Metric; Manufacturer Part Number SDCL1005C10NJTDF
L101: 15u; L_Sunlord_MWSA0603S; Manufacturer Part Number MWSA0603S-150MT
R100: 10R; R_0805_2012Metric; Manufacturer Part Number 0805W8F100JT5E
R101: 100k; R_0402_1005Metric; Manufacturer Part Number 0402WGF1003TCE
R102: 22k; R_0402_1005Metric; Manufacturer Part Number 0402WGF2202TCE
R103, R104, R105: 1k; R_0402_1005Metric; Manufacturer Part Number 0402WGF1001TCE
U100: HT7533-1; SOT-89-3; Manufacturer Part Number HT7533-1
U101: TLV62569DBV; SOT-23-5; Manufacturer Part Number TLV62569DBVR
U102: MCP6001T-E/OT; SOT-23-5; Manufacturer Part Number MCP6001T-E/OT

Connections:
+3.3VA: C103.1, C108.1, R104.2, U100.3 (VOUT), U102.5 (V+); also elsewhere on the board
+3V3: C105.1, C106.1, D100.2 (A), L101.2, R101.2; also elsewhere on the board
+5V: C101.1, C104.1, L100.2, R100.2, U101.1 (EN), U101.4 (VIN); also elsewhere on the board
/Power/+5V_FILT: C102.1, R100.1, U100.2 (VIN)
/Power/BUCK_FB: C106.2, R101.1, R102.2, U101.5 (FB)
/Power/BUCK_SW: L101.1, U101.3 (SW)
/Power/LED_PWR_K: D100.1 (K), R103.2
/Power/VREF: C107.1, R104.1, R105.2, U102.3 (+)
GND: C100.2, C101.2, C102.2, C103.2, C104.2, C105.2, C107.2, C108.2, R102.1, R103.1, R105.1, U100.1 (GND), U101.2 (GND), U102.2 (V-); also elsewhere on the board
VBUS: C100.1, L100.1; also elsewhere on the board
VCOM: U102.1, U102.4 (-); also elsewhere on the board

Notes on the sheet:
DCR=0R15
C(in/out)>10uF
V(out)=0.6*(1+100k/22k)=3.327V
I(DC)=500mA
Bias Generator
LP filter: fc=15Hz
100mA max.
f(sw)=1.5MHz
VBUS power comes from USB Type C connector (schematic page 2)
P(R)>1/8W
I(load)=0.25A max
Input Filtering & Analogue and Digital Supplies
[1] Power
WEBENCH Tools

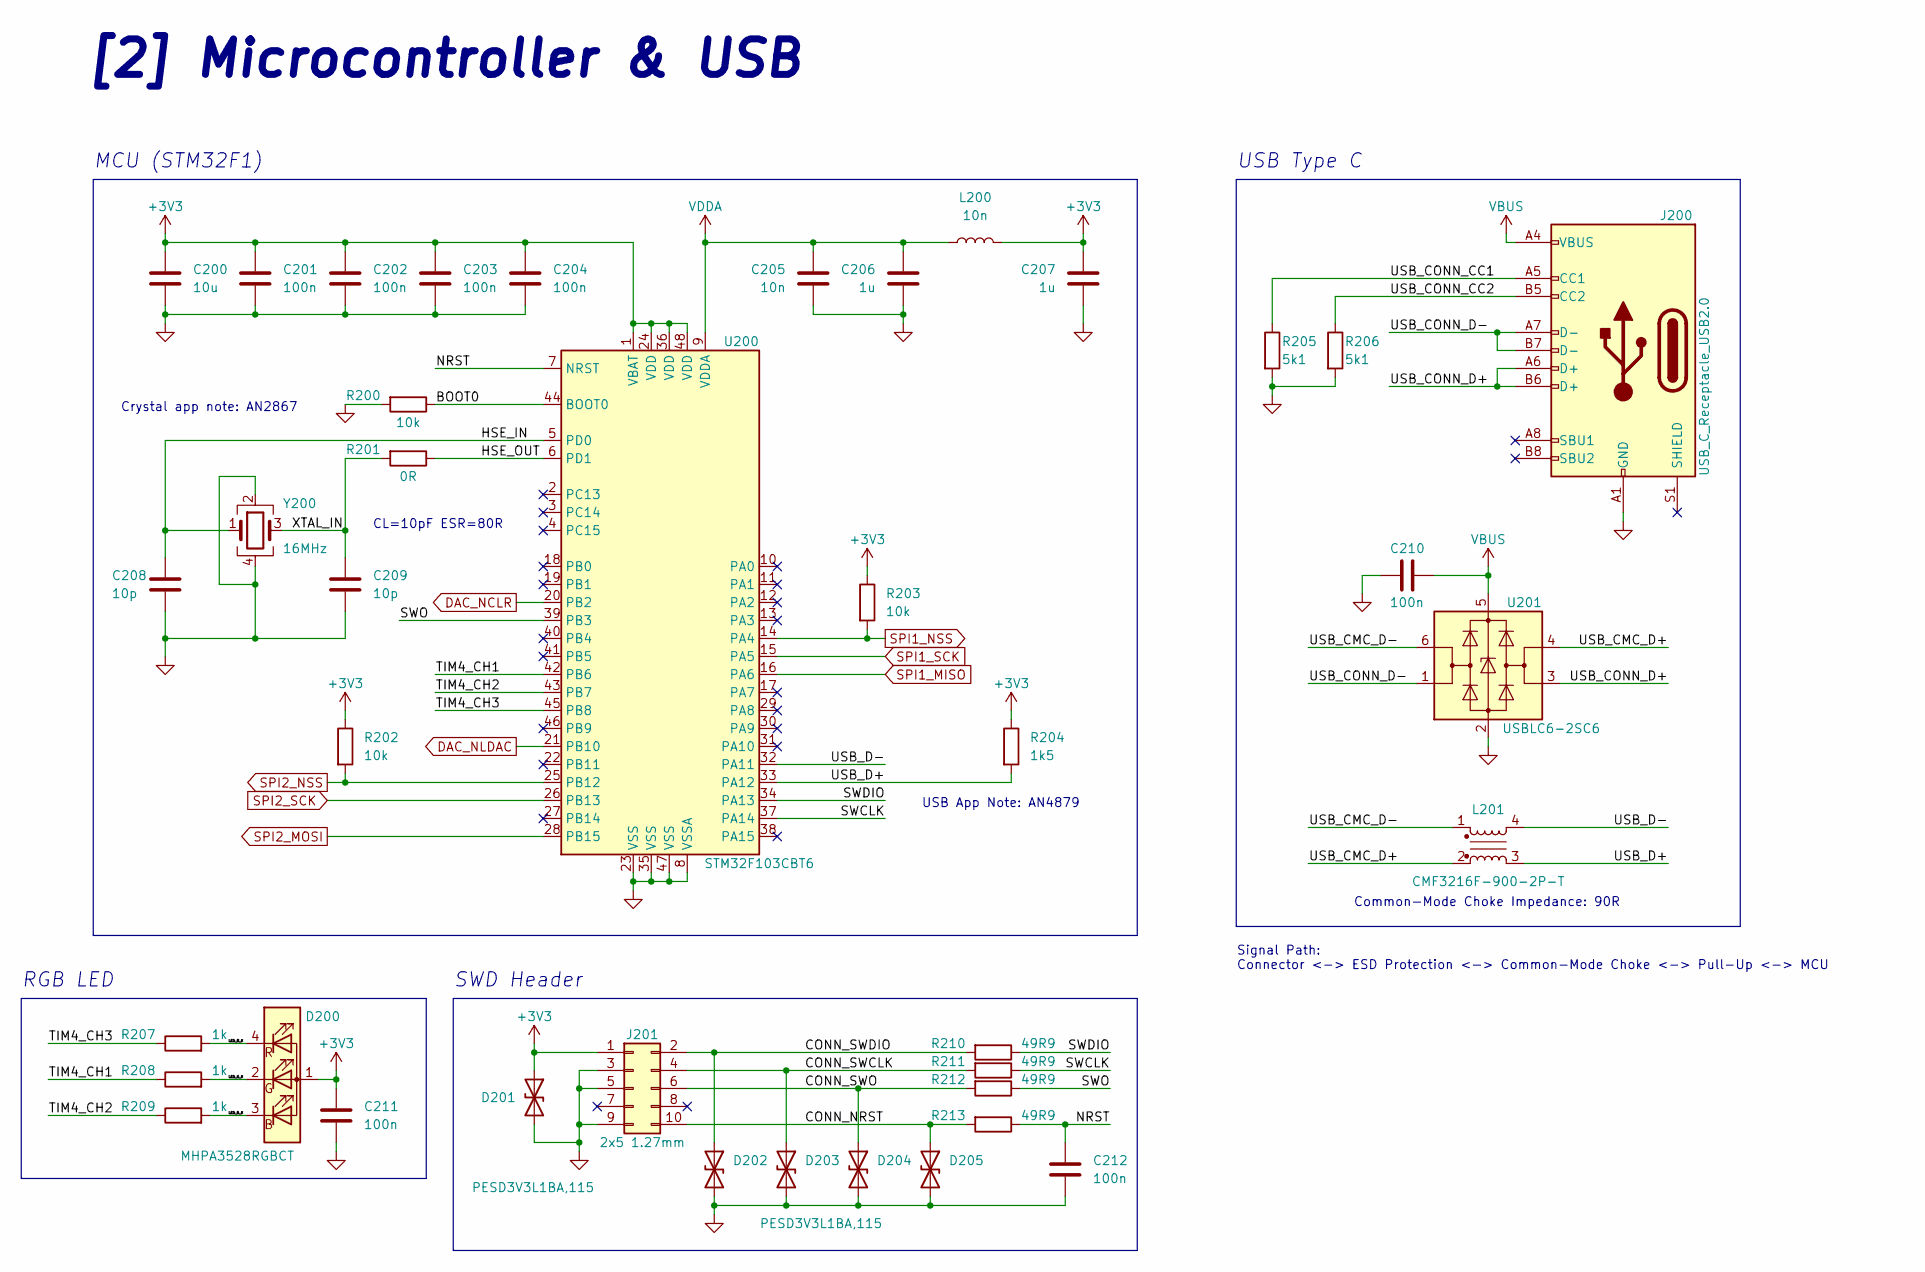
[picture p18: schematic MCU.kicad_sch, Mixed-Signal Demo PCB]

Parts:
C200: 10u; C_0603_1608Metric; Manufacturer Part Number CL10A106MA8NRNC
C201, C202, C203, C204, C210, C211, C212: 100n; C_0402_1005Metric; Manufacturer Part Number CL05B104KO5NNNC
C205: 10n; C_0402_1005Metric; Manufacturer Part Number CL05B103KB5NNNC
C206, C207: 1u; C_0603_1608Metric; Manufacturer Part Number CL10A105KB8NNNC
C208, C209: 10p; C_0402_1005Metric; Manufacturer Part Number CL05C100JB5NNNC
D200: MHPA3528RGBCT; Manufacturer Part Number MHPA3528RGBCT
D201, D202, D203, D204, D205: PESD3V3L1BA,115; D_SOD-323; Manufacturer Part Number PESD3V3L1BA,115
J200: USB_C_Receptacle_USB2.0; USB_C_Receptacle_HRO_TYPE-C-31-M-12; Manufacturer Part Number TYPE-C-31-M-12
J201: 2x5 1.27mm; PinHeader_2x05_P1.27mm_Vertical_SMD; Manufacturer Part Number FTSH-105-01-F-DV-K-TR
L200: 10n; L_0402_1005Metric; Manufacturer Part Number SDCL1005C10NJTDF
L201: CMF3216F-900-2P-T; L_CommonModeChoke_CMF3216F-900-2P-T; Manufacturer Part Number CMF3216F-900-2P-T
R200, R202, R203: 10k; R_0402_1005Metric; Manufacturer Part Number 0402WGF1002TCE
R201: 0R; R_0402_1005Metric; Manufacturer Part Number 0402WGF0000TCE
R204: 1k5; R_0402_1005Metric; Manufacturer Part Number 0402WGF1501TCE
R205, R206: 5k1; R_0402_1005Metric; Manufacturer Part Number 0402WGF5101TCE
R207, R208, R209: 1k; R_0402_1005Metric; Manufacturer Part Number 0402WGF1001TCE
R210, R211, R212, R213: 49R9; R_0402_1005Metric; Manufacturer Part Number 0402WGF499JTCE
U200: STM32F103CBT6; LQFP-48_7x7mm_P0.5mm; Manufacturer Part Number STM32F103CBT6
U201: USBLC6-2SC6; SOT-23-6; Manufacturer Part Number USBLC6-2SC6
Y200: 16MHz; Crystal_SMD_3225-4Pin_3.2x2.5mm; Manufacturer Part Number 7M16000017

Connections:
+3V3: C200.1, C201.1, C202.1, C203.1, C204.1, C207.1, C211.1, D200.1 (A), D201.1 (A1), J201.1 (Vcc), L200.2, R202.1, R203.1, R204.1, U200.1 (VBAT), U200.24 (VDD), U200.36 (VDD), U200.48 (VDD); also elsewhere on the board
/MCU/BOOT0: R200.1, U200.44 (BOOT0)
/MCU/CONN_NRST: D205.1 (A1), J201.10 (NRST), R213.2
/MCU/CONN_SWCLK: D203.1 (A1), J201.4 (SWDCLK), R211.2
/MCU/CONN_SWDIO: D202.1 (A1), J201.2 (SWDIO), R210.2
/MCU/CONN_SWO: D204.1 (A1), J201.6 (SWO), R212.2
/MCU/HSE_IN: C208.1, U200.5 (PD0), Y200.1
/MCU/HSE_OUT: R201.1, U200.6 (PD1)
/MCU/LED_B_K: D200.3 (BK), R209.2
/MCU/LED_G_K: D200.2 (GK), R208.2
/MCU/LED_R_K: D200.4 (RK), R207.2
/MCU/NRST: C212.1, R213.1, U200.7 (NRST)
/MCU/SWCLK: R211.1, U200.37 (PA14)
/MCU/SWDIO: R210.1, U200.34 (PA13)
/MCU/SWO: R212.1, U200.39 (PB3)
/MCU/TIM4_CH1: R208.1, U200.42 (PB6)
/MCU/TIM4_CH2: R209.1, U200.43 (PB7)
/MCU/TIM4_CH3: R207.1, U200.45 (PB8)
/MCU/USB_CMC_D+: L201.2, U201.4 (I/O2)
/MCU/USB_CMC_D-: L201.1, U201.6 (I/O1)
/MCU/USB_CONN_CC1: J200.A5 (CC1), R205.1
/MCU/USB_CONN_CC2: J200.B5 (CC2), R206.1
/MCU/USB_CONN_D+: J200.A6 (D+), J200.B6 (D+), U201.3 (I/O2)
/MCU/USB_CONN_D-: J200.A7 (D-), J200.B7 (D-), U201.1 (I/O1)
/MCU/USB_D+: L201.3, R204.2, U200.33 (PA12)
/MCU/USB_D-: L201.4, U200.32 (PA11)
/MCU/XTAL_IN: C209.1, R201.2, Y200.3
DAC_NCLR: U200.20 (PB2); also elsewhere on the board
DAC_NLDAC: U200.21 (PB10); also elsewhere on the board
GND: C200.2, C201.2, C202.2, C203.2, C204.2, C205.2, C206.2, C207.2, C208.2, C209.2, C210.2, C211.2, C212.2, D201.2 (A2), D202.2 (A2), D203.2 (A2), D204.2 (A2), D205.2 (A2), J200.A1 (GND), J200.A12 (GND), J200.B1 (GND), J200.B12 (GND), J201.3 (GND), J201.5 (GND), J201.9 (GNDDetect), R200.2, R205.2, R206.2, U200.8 (VSSA), U200.23 (VSS), U200.35 (VSS), U200.47 (VSS), U201.2 (GND), Y200.2, Y200.4; also elsewhere on the board
SPI1_MISO: U200.16 (PA6); also elsewhere on the board
SPI1_NSS: R203.2, U200.14 (PA4); also elsewhere on the board
SPI1_SCK: U200.15 (PA5); also elsewhere on the board
SPI2_MOSI: U200.28 (PB15); also elsewhere on the board
SPI2_NSS: R202.2, U200.25 (PB12); also elsewhere on the board
SPI2_SCK: U200.26 (PB13); also elsewhere on the board
VBUS: C210.1, J200.A4 (VBUS), J200.A9 (VBUS), J200.B4 (VBUS), J200.B9 (VBUS), U201.5 (VBUS); also elsewhere on the board
VDDA: C205.1, C206.1, L200.1, U200.9 (VDDA)

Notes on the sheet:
Signal Path: Connector <-> ESD Protection <-> Common-Mode Choke <-> Pull-Up <-> MCU
RGB LED
Crystal app note: AN2867
SWD Header
USB App Note: AN4879
Common-Mode Choke Impedance: 90R
[2] Microcontroller & USB
CL=10pF ESR=80R
MCU (STM32F1)
USB Type C

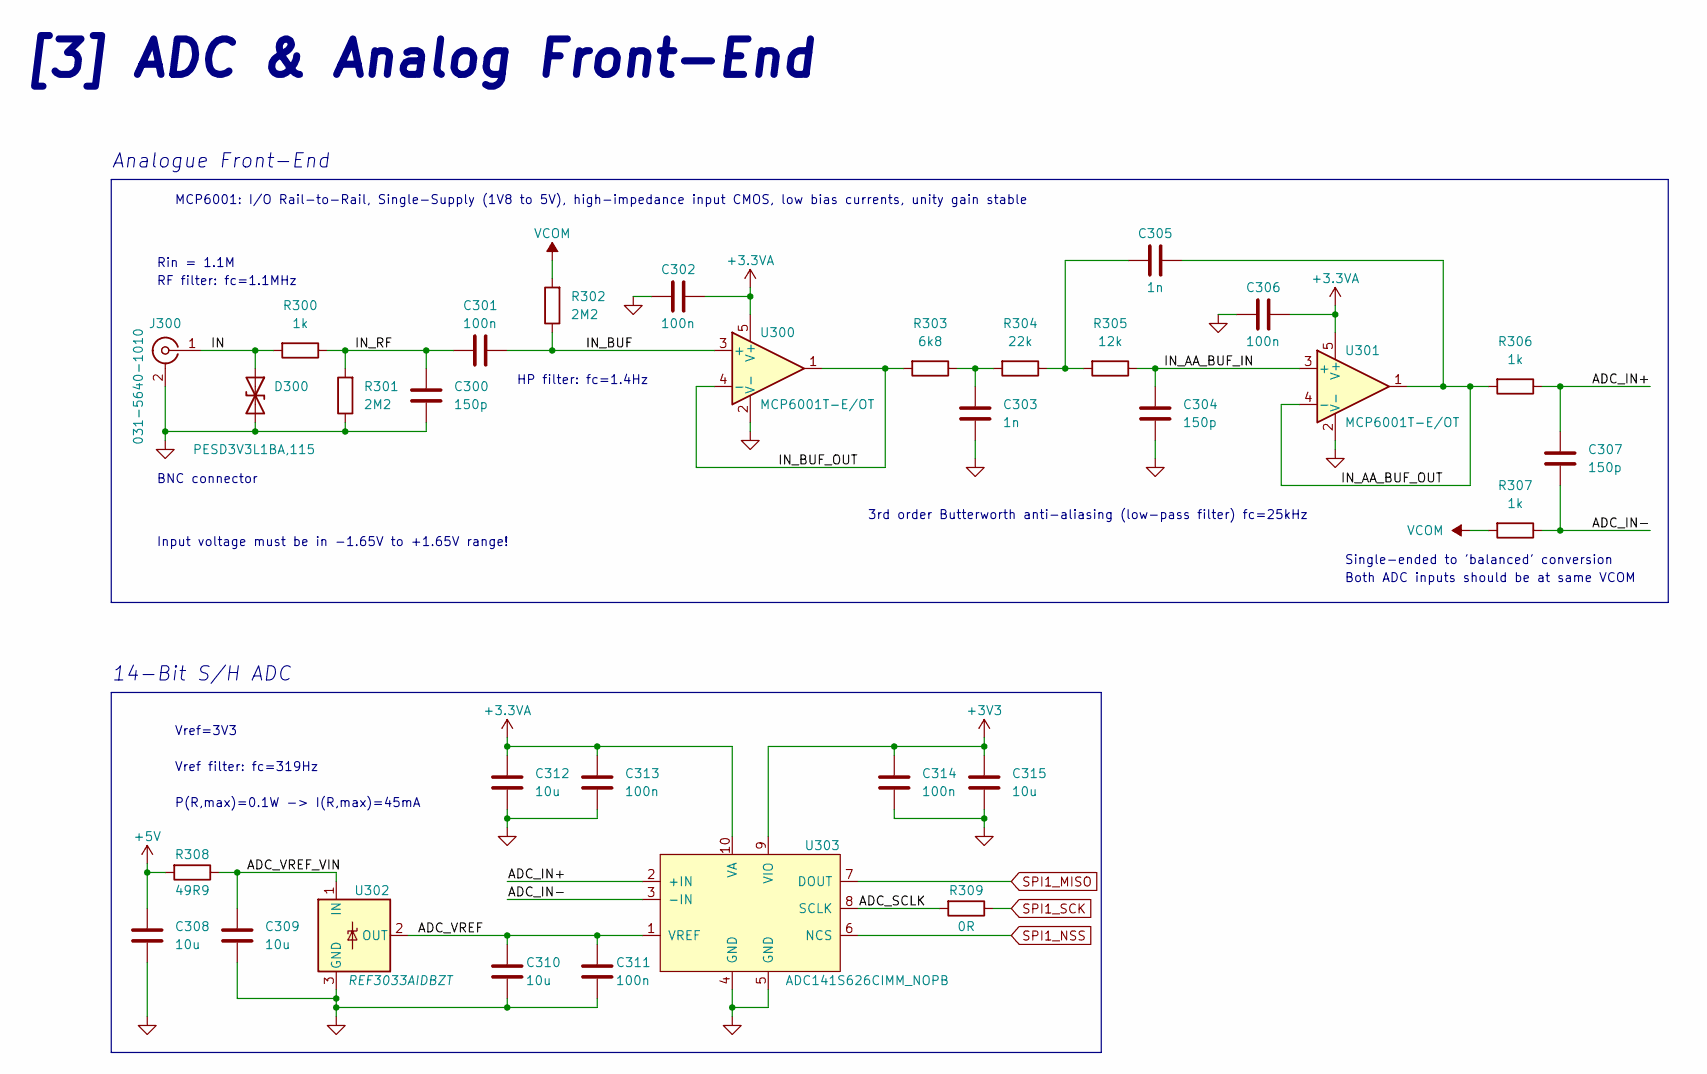
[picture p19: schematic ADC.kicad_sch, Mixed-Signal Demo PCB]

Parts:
C300, C304, C307: 150p; C_0402_1005Metric; Manufacturer Part Number CL05C151JB5NNNC
C301, C302, C306, C311, C313, C314: 100n; C_0402_1005Metric; Manufacturer Part Number CL05B104KO5NNNC
C303, C305: 1n; C_0402_1005Metric; Manufacturer Part Number 0402B102K500NT
C308, C309, C310, C312, C315: 10u; C_0603_1608Metric; Manufacturer Part Number CL10A106MA8NRNC
D300: PESD3V3L1BA,115; D_SOD-323; Manufacturer Part Number PESD3V3L1BA,115
J300: 031-5640-1010; AMPHENOL-BNC-031-5640-1010; Manufacturer Part Number 031-5640
R300, R306, R307: 1k; R_0402_1005Metric; Manufacturer Part Number 0402WGF1001TCE
R301, R302: 2M2; R_0402_1005Metric; Manufacturer Part Number 0402WGF2204TCE
R303: 6k8; R_0402_1005Metric; Manufacturer Part Number 0402WGF6801TCE
R304: 22k; R_0402_1005Metric; Manufacturer Part Number 0402WGF2202TCE
R305: 12k; R_0402_1005Metric; Manufacturer Part Number 0402WGF1202TCE
R308: 49R9; R_0402_1005Metric; Manufacturer Part Number 0402WGF499JTCE
R309: 0R; R_0402_1005Metric; Manufacturer Part Number 0402WGF0000TCE
U300, U301: MCP6001T-E/OT; SOT-23-5; Manufacturer Part Number MCP6001T-E/OT
U302: REF3033AIDBZT; SOT-23; Manufacturer Part Number REF3033AIDBZT
U303: ADC141S626CIMM_NOPB; VSSOP-10_3x3mm_P0.5mm; Manufacturer Part Number ADC141S626CIMM/NOPB

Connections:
+3.3VA: C302.1, C306.1, C312.1, C313.1, U300.5 (V+), U301.5 (V+), U303.10 (VA); also elsewhere on the board
+3V3: C314.1, C315.1, U303.9 (VIO); also elsewhere on the board
+5V: C308.1, R308.2; also elsewhere on the board
/ADC/ADC_IN+: C307.1, R306.1, U303.2 (+IN)
/ADC/ADC_IN-: C307.2, R307.1, U303.3 (-IN)
/ADC/ADC_SCLK: R309.2, U303.8 (SCLK)
/ADC/ADC_VREF: C310.1, C311.1, U302.2 (OUT), U303.1 (VREF)
/ADC/ADC_VREF_VIN: C309.1, R308.1, U302.1 (IN)
/ADC/IN: D300.1 (A1), J300.1 (In), R300.2
/ADC/IN_AA_BUF_IN: C304.1, R305.1, U301.3 (+)
/ADC/IN_AA_BUF_OUT: C305.2, R306.2, U301.1, U301.4 (-)
/ADC/IN_BUF: C301.1, R302.1, U300.3 (+)
/ADC/IN_BUF_OUT: R303.2, U300.1, U300.4 (-)
/ADC/IN_RF: C300.1, C301.2, R300.1, R301.2
GND: C300.2, C302.2, C303.2, C304.2, C306.2, C308.2, C309.2, C310.2, C311.2, C312.2, C313.2, C314.2, C315.2, D300.2 (A2), J300.2 (Ext), R301.1, U300.2 (V-), U301.2 (V-), U302.3 (GND), U303.4 (GND), U303.5 (GND); also elsewhere on the board
unnamed: C303.1, R303.1, R304.2
unnamed: C305.1, R304.1, R305.2
SPI1_MISO: U303.7 (DOUT); also elsewhere on the board
SPI1_NSS: U303.6 (NCS); also elsewhere on the board
SPI1_SCK: R309.1; also elsewhere on the board
VCOM: R302.2, R307.2; also elsewhere on the board

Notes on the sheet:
HP filter: fc=1.4Hz
Both ADC inputs should be at same VCOM
BNC connector
Rin = 1.1M
14-Bit S/H ADC
Vref filter: fc=319Hz
Input voltage must be in -1.65V to +1.65V range!
Analogue Front-End
Single-ended to 'balanced' conversion
RF filter: fc=1.1MHz
3rd order Butterworth anti-aliasing (low-pass filter) fc=25kHz
MCP6001: I/O Rail-to-Rail, Single-Supply (1V8 to 5V), high-impedance input CMOS, low bias currents, unity gain stable
P(R,max)=0.1W -> I(R,max)=45mA
Vref=3V3
[3] ADC & Analog Front-End

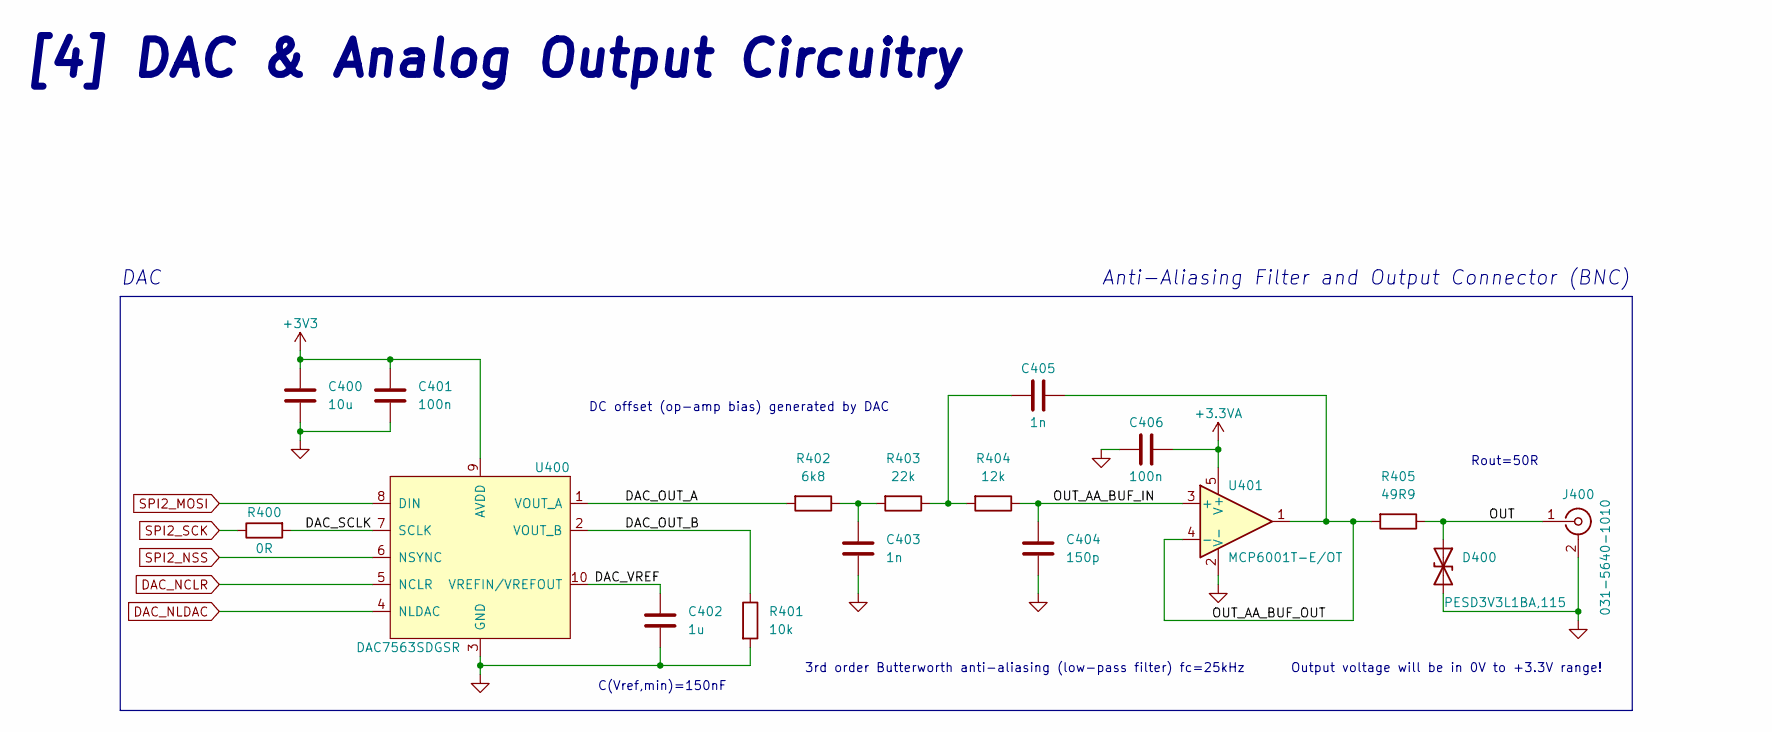
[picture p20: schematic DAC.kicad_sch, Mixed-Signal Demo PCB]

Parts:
C400: 10u; C_0603_1608Metric; Manufacturer Part Number CL10A106MA8NRNC
C401, C406: 100n; C_0402_1005Metric; Manufacturer Part Number CL05B104KO5NNNC
C402: 1u; C_0603_1608Metric; Manufacturer Part Number CL10A105KB8NNNC
C403, C405: 1n; C_0402_1005Metric; Manufacturer Part Number 0402B102K500NT
C404: 150p; C_0402_1005Metric; Manufacturer Part Number CL05C151JB5NNNC
D400: PESD3V3L1BA,115; D_SOD-323; Manufacturer Part Number PESD3V3L1BA,115
J400: 031-5640-1010; AMPHENOL-BNC-031-5640-1010; Manufacturer Part Number 031-5640
R400: 0R; R_0402_1005Metric; Manufacturer Part Number 0402WGF0000TCE
R401: 10k; R_0402_1005Metric; Manufacturer Part Number 0402WGF1002TCE
R402: 6k8; R_0402_1005Metric; Manufacturer Part Number 0402WGF6801TCE
R403: 22k; R_0402_1005Metric; Manufacturer Part Number 0402WGF2202TCE
R404: 12k; R_0402_1005Metric; Manufacturer Part Number 0402WGF1202TCE
R405: 49R9; R_0402_1005Metric; Manufacturer Part Number 0402WGF499JTCE
U400: DAC7563SDGSR; VSSOP-10_3x3mm_P0.5mm; Manufacturer Part Number DAC7563TDGSR
U401: MCP6001T-E/OT; SOT-23-5; Manufacturer Part Number MCP6001T-E/OT

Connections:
+3.3VA: C406.1, U401.5 (V+); also elsewhere on the board
+3V3: C400.1, C401.1, U400.9 (AVDD); also elsewhere on the board
/DAC/DAC_OUT_A: R402.2, U400.1 (VOUT_A)
/DAC/DAC_OUT_B: R401.1, U400.2 (VOUT_B)
/DAC/DAC_SCLK: R400.2, U400.7 (SCLK)
/DAC/DAC_VREF: C402.1, U400.10 (VREFIN/VREFOUT)
/DAC/OUT: D400.1 (A1), J400.1 (In), R405.1
/DAC/OUT_AA_BUF_IN: C404.1, R404.1, U401.3 (+)
/DAC/OUT_AA_BUF_OUT: C405.2, R405.2, U401.1, U401.4 (-)
DAC_NCLR: U400.5 (NCLR); also elsewhere on the board
DAC_NLDAC: U400.4 (NLDAC); also elsewhere on the board
GND: C400.2, C401.2, C402.2, C403.2, C404.2, C406.2, D400.2 (A2), J400.2 (Ext), R401.2, U400.3 (GND), U401.2 (V-); also elsewhere on the board
unnamed: C403.1, R402.1, R403.2
unnamed: C405.1, R403.1, R404.2
SPI2_MOSI: U400.8 (DIN); also elsewhere on the board
SPI2_NSS: U400.6 (NSYNC); also elsewhere on the board
SPI2_SCK: R400.1; also elsewhere on the board

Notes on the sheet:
[4] DAC & Analog Output Circuitry
Anti-Aliasing Filter and Output Connector (BNC)
Rout=50R
Output voltage will be in 0V to +3.3V range!
DAC
C(Vref,min)=150nF
3rd order Butterworth anti-aliasing (low-pass filter) fc=25kHz
DC offset (op-amp bias) generated by DAC

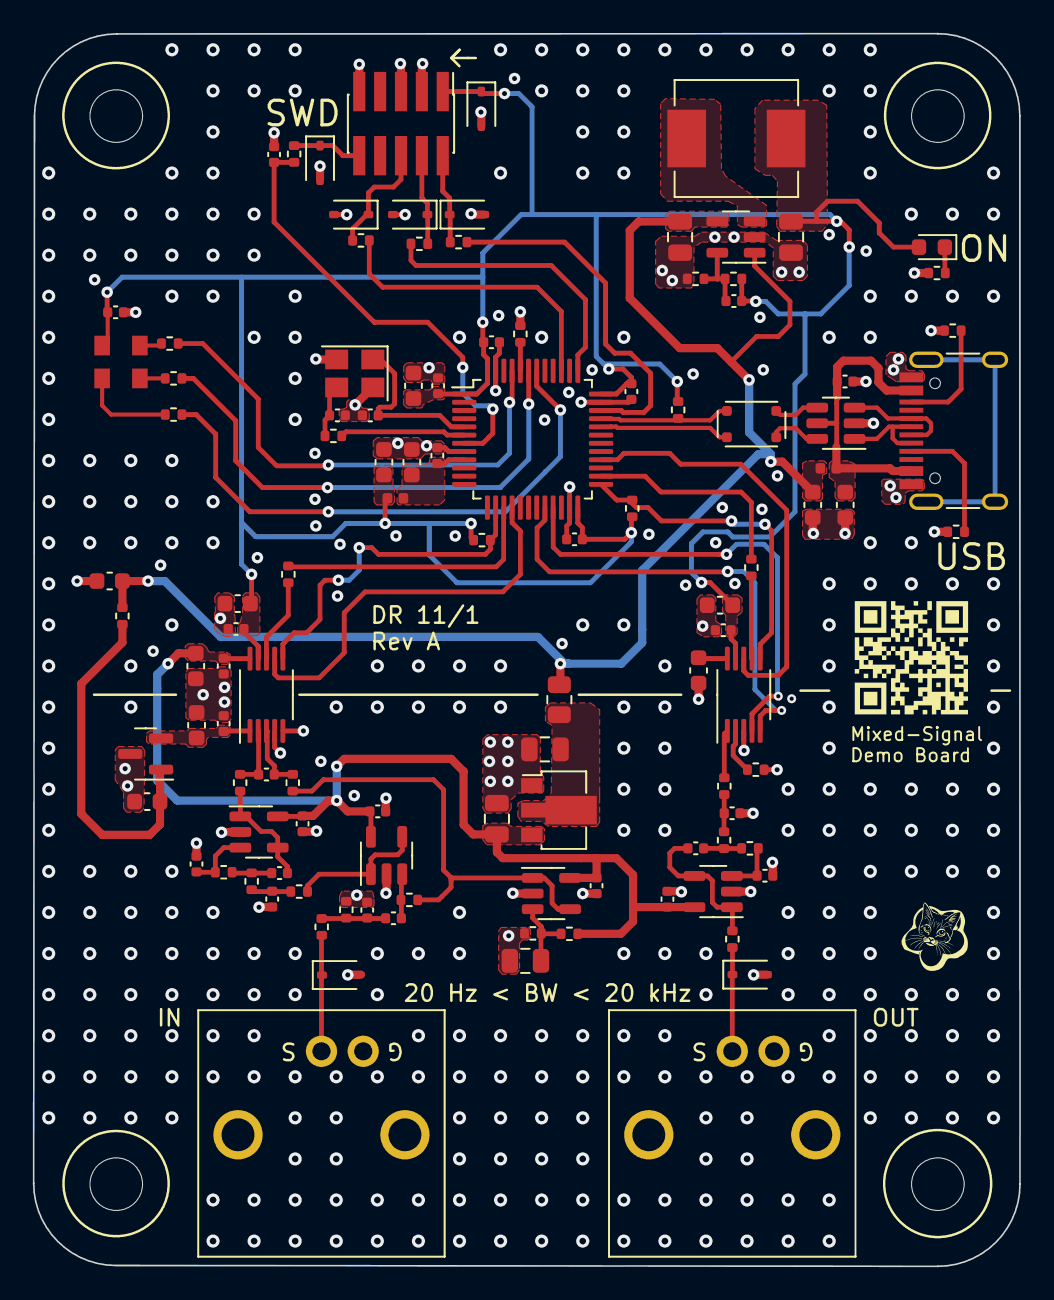
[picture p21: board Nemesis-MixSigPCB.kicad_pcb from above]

Board: 4 copper layers, 60.0 x 75.0 mm, 114 parts (0 on the bottom side), 68 nets.

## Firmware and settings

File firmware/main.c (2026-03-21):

#include <stdint.h>

// STM32F405 Register Base Addresses
#define RCC_BASE	0x40023800
#define GPIOA_BASE	0x40020000
#define GPIOB_BASE	0x40020400
#define GPIOC_BASE	0x40020800
#define USART3_BASE	0x40004800
#define	ADC1_BASE	0x40012000
#define DAC_BASE	0x40007400
#define TIM2_BASE	0x40000000
#define DMA2_BASE	0x40026400


//RCC Registers
#define RCC_CR			(*((volatile uint32_t *)(RCC_BASE + 0x00)))
#define RCC_PLLCFGR		(*((volatile uint32_t *)(RCC_BASE + 0x04)))
#define RCC_CFGR		(*((volatile uint32_t *)(RCC_BASE + 0x08)))
#define RCC_AHB1ENR		(*((volatile uint32_t *)(RCC_BASE + 0x30)))
#define RCC_APB1ENR		(*((volatile uint32_t *)(RCC_BASE + 0x40)))
#define RCC_APB2ENR		(*((volatile uint32_t *)(RCC_BASE + 0x44)))


//TIM2 Registers
#define TIM2_CR1		(*((volatile uint32_t *)(TIM2_BASE + 0x00)))
#define TIM2_CR2		(*((volatile uint32_t *)(TIM2_BASE + 0x04)))
#define TIM2_PSC		(*((volatile uint32_t *)(TIM2_BASE + 0x28)))
#define TIM2_ARR		(*((volatile uint32_t *)(TIM2_BASE + 0x2C)))
#define TIM2_EGR		(*((volatile uint32_t *)(TIM2_BASE + 0x14)))


//DMA2 Registers
#define DMA_S0CR		(*((volatile uint32_t *)(DMA2_BASE + 0x10)))
#define DMA_S0NDTR		(*((volatile uint32_t *)(DMA2_BASE + 0x14)))
#define DMA_S0PAR		(*((volatile uint32_t *)(DMA2_BASE + 0x18)))
#define DMA_S0M0AR		(*((volatile uint32_t *)(DMA2_BASE + 0x1C)))
#define DMA_S0M1AR		(*((volatile uint32_t *)(DMA2_BASE + 0x20)))
#define DMA2_LISR  		(*((volatile uint32_t *)(DMA2_BASE + 0x00)))
#define DMA2_LIFCR  	(*((volatile uint32_t *)(DMA2_BASE + 0x08)))


//GPIOA Registers
#define GPIOA_MODER 	(*((volatile uint32_t *)(GPIOA_BASE + 0x00)))

//GPIOB Registers
#define GPIOB_MODER 	(*((volatile uint32_t *)(GPIOB_BASE + 0x00)))
#define	GPIOB_AFRH		(*((volatile uint32_t *)(GPIOB_BASE + 0x24)))

//GPIOC Registers
#define GPIOC_MODER 	(*((volatile uint32_t *)(GPIOC_BASE + 0x00)))
#define GPIOC_ODR		(*((volatile uint32_t *)(GPIOC_BASE + 0x14)))


//USART3 Registers (keeping for later)
#define USART3_SR		(*((volatile uint32_t *)(USART3_BASE + 0x00)))
#define USART3_DR		(*((volatile uint32_t *)(USART3_BASE + 0x04)))
#define USART3_BRR		(*((volatile uint32_t *)(USART3_BASE + 0x08)))
#define USART3_CR1		(*((volatile uint32_t *)(USART3_BASE + 0x0C)))


//ADC1 Registers
#define ADC1_SR			(*((volatile uint32_t *)(ADC1_BASE + 0x00)))
#define ADC1_CR1		(*((volatile uint32_t *)(ADC1_BASE + 0x04)))
#define ADC1_CR2		(*((volatile uint32_t *)(ADC1_BASE + 0x08)))
#define ADC1_SMPR2		(*((volatile uint32_t *)(ADC1_BASE + 0x14)))
#define ADC1_SQR3		(*((volatile uint32_t *)(ADC1_BASE + 0x34)))
#define ADC1_DR			(*((volatile uint32_t *)(ADC1_BASE + 0x4C)))

//DAC Registers
#define DAC_CR			(*((volatile uint32_t *)(DAC_BASE + 0x00)))
#define DAC_DHR12R2		(*((volatile uint32_t *)(DAC_BASE + 0x14)))


//ADC Common Register
#define	ADC_CCR			(*((volatile uint32_t *)(0x40012300 + 0x04)))

//FPU Enable
#define FPU_CPACR		(*((volatile uint32_t *)0xE000ED88))	//ARM architecture-defined (Every Cortex-M4 chip in the world has this FPU control register address)

//Double buffers - DMA writes here, CPU reads here
#define BUFFER_SIZE 240

volatile uint16_t	buffer_A[BUFFER_SIZE];
volatile uint16_t	buffer_B[BUFFER_SIZE];
volatile uint8_t	buffer_ready = 255;		//255 = no buffer ready yet


//Utility
void delay(volatile uint32_t count){
	while(count--);
}

//ADC INIT
void adc_init(void) {

	//Enable GPIOA and ADC1 clocks
	RCC_AHB1ENR |= (1 << 0);	//GPIOA
	RCC_APB2ENR |= (1 << 8);

	//Set PA4 to analog mode (11 in MODER bits 8-9)
	GPIOA_MODER |= (3 << 8);

	//Set ADC pres-calar to /4
	ADC_CCR |= (1 << 16);

	//Set sample time for channel 4 to 480 cycles (slowest, most accurate)
	ADC1_SMPR2 |= (7 << 12);

	//Set channel 4 as first conversion in sequence
	ADC1_SQR3 = 4;

	//Enable ADC
	ADC1_CR2 |= (1 << 0);	//enable ADC1
	delay(10000);			//stabilize
	ADC1_CR2 |= (6 << 24);	//EXTSEL = 0110, TIM2 TRGO
	ADC1_CR2 |= (1 << 28); 	//EXTEN = 01, rising edge
	ADC1_CR2 |= (1 << 8);  // DMA enable
	ADC1_CR2 |= (1 << 9);  // DDS - keep DMA requests continuous

	//Wait for ADC to stabilize
	delay(10000);

}

//Timer Initialize
void timer_init(void) {

	//Enable Timer2 clock first
	RCC_APB1ENR |= (1 << 0);

	//Configure before starting
	TIM2_CR2 |= (1 << 5);	//MMS = 010, TRGO on update
	TIM2_PSC = 0;			//No prescalar, full 16 MHz
	TIM2_ARR = 332;			// 16 MHz / 333 = ~48.048 kHz
	TIM2_EGR |= (1 << 0);	//Load PSC and ARR immediately

	//Start the timer last
	TIM2_CR1 |= (1 << 0);	//CEN - counter enable
}


//Initialize DMA
void dma_init(void) {

	RCC_AHB1ENR |= (1 << 22);	//DMA2 clock enable
	DMA_S0CR &= ~ (1 << 0);
	while(DMA_S0CR & (1 << 0));	//wait until hardware confirms disabled

	// Clear CHSEL bits (channel 0)
	DMA_S0CR &= ~(0x7 << 25);

	// Set all configuration bits in S0CR
	DMA_S0CR |= (1 << 18);  // DBM - double buffer mode
	DMA_S0CR |= (1 << 13);  // MSIZE = 01, 16-bit memory size
	DMA_S0CR |= (1 << 11);  // PSIZE = 01, 16-bit peripheral size
	DMA_S0CR |= (1 << 10);  // MINC - memory increment enable
	DMA_S0CR |= (1 << 4);   // TCIE - transfer complete interrupt
	// DIR = 00 (peripheral to memory) - already 0 at reset
	// PINC = 0 (peripheral address fixed) - already 0 at reset

	DMA_S0PAR  = (uint32_t)(ADC1_BASE + 0x4C);  // ADC1_DR address
	DMA_S0M0AR = (uint32_t)buffer_A;             // buffer A
	DMA_S0M1AR = (uint32_t)buffer_B;             // buffer B
	DMA_S0NDTR = BUFFER_SIZE;                    // 240 transfers

	// Enable DMA2 Stream0 interrupt in NVIC
	// DMA2_Stream0 is IRQ 56
	*((volatile uint32_t *)0xE000E100 + (56/32)) |= (1 << (56 % 32));

	DMA_S0CR |= (1 << 0);  // EN - enable stream
}

void DMA2_Stream0_IRQHandler(void) {
	if (DMA2_LISR & (1 << 5)) {
		DMA2_LIFCR |= (1 << 5);
		if (DMA_S0CR & (1 << 19)) {
		    buffer_ready = 0;  // CT=1 means DMA switched to buffer B, so A is ready
		} else {
		    buffer_ready = 1;  // CT=0 means DMA switched to buffer A, so B is ready
		}

		// Simple pass-through - write ADC samples to DAC
		// Output all samples to DAC
		volatile uint16_t *buf = (buffer_ready == 0) ? buffer_A : buffer_B;
		for(int i = 0; i < BUFFER_SIZE; i++) {
		    DAC_DHR12R2 = buf[i];
		    // Small delay for DAC to settle
		    for(volatile int d = 0; d < 14; d++);
		}
	}
}

void dac_init(void) {

	//DAC Enable
	RCC_APB1ENR |= (1 << 29);

	//Set GPIO 12 (PA5) to Analog for DAC
	GPIOA_MODER |= (3 << 10);	//This is PA 5 (2x pin# and 11 for analog)

	DAC_CR |= (1 << 16);		//EN2 - Enable channel 2 DAC

}

int main(void) {

	//Enable FPU (floating point) - full access to CP10 and CP11
	FPU_CPACR |= (0xF << 20);

	adc_init();
	timer_init();
	dma_init();
	dac_init();

	//Enable GPIOC, set PC1 as output (red LED)
	RCC_AHB1ENR |= (1 << 2);
	GPIOC_MODER &= ~(3 << 2);
	GPIOC_MODER |= (1 << 2);

	volatile uint16_t *active_buffer;

	for(;;) {

        // Wait for DMA to finish filling a buffer
        while(buffer_ready == 255);  // 255 = no buffer ready yet

        // Point to whichever buffer is ready
        if (buffer_ready == 0) {
            active_buffer = buffer_A;
        } else {
            active_buffer = buffer_B;
        }

        // Mark as processed
        buffer_ready = 255;

        // Toggle LED to show processing is happening
        GPIOC_ODR ^= (1 << 1);

	}
}

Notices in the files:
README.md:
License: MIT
